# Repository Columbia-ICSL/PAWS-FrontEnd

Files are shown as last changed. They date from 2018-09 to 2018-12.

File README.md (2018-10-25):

# README #

This repository contains the code, pcb design, and documentation for the **Pedestrian Audio Wearable System (PAWS)** front-end, headset, embedded platform.

PAWS is a low-power connected system for improving pedestrian safety in current and future smart cities. PAWS uses microphones embedded into a headset combined with low-power feature extraction, signal processing, and machine learning, for detecting, localizing, and providing alerts of oncoming vehicles to pedestrians in noisy environments.

* Note: The PAWS project was at some point known as SEUS, which is why SEUS is used at some points rather than PAWS.

The contents of this repository are summarized below.

* **PAWS**: Contains the PAWS front-end source code and designs.
	* nordic_nRF52: Contains the project files for building and flashing the firmware for the Nordic nRF52 BLE chip used for wireless communication with the PAWS smartphone application.
	* stm32f4: Contains the project files for building and flashing the firmware for the STM32F4 chip used for feature extraction in PAWS.
	* pcb: Contains the pcb schematics, designed using Altium Circuitmaker, for the PAWS embedded platform as well as documentation for how to maintain the PAWS headset. The platform uses a STM32F4 Chip for feature extraction + the Nordic nRF52 BLE chip for transmission to the smartphone.
* **PAWS_LE**: Contains the PAWS LE front-end source code and designs. PAWS LE is the low-energy variant of PAWS and has finer granularity car localization, achieved by using a technique called *Angle via Polygonal Regression (AvPR)*.
	* nordic_nRF52: Contains the project files for building and flashing the firmware for the Nordic nRF52 BLE chip used for wireless communication with the PAWS LE smartphone application.
	* pcb: Contains the pcb schematics, designed using Altium Circuitmaker, for the PAWS LE embedded platform. The platform uses a custom-build ASIC for relative delay extraction + the Nordic nRF52 BLE chip for transmission to the smartphone.

# Reproducing the PAWS system

To reproduce the PAWS system, you must first install the PAWS smartphone application; details on how to do this can be found in the PAWS-Smartphone repository.

Next, you must reproduce the PAWS front-end PCB. Details on how to do this can be found in the **./PAWS** folder.

# Reproducing the PAWS LE System

To reproduce the PAWS LE system, you must first install the PAWS LE smartphone application; details on how to do this can be found in the [PAWS-Smartphone repository](https://github.com/Columbia-ICSL/PAWS-Smartphone).

Next, you must reproduce the PAWS LE front-end PCB. Details on how to do this can be found in the **./PAWS_LE** folder.

# More About the PAWS Project
To learn more about PAWS, please visit our [project page](http://icsl.ee.columbia.edu/projects/seus), or contact us at: [stephen.xia@columbia.edu](stephen.xia@columbia.edu). 	 
	
This repository is part of the **Pedestrian Audio Wearable System (PAWS)** project of the **Intelligent and Connected Systems Lab (ICSL)**, Columbia University.
For more information about our latest projects, please visit our [group website](http://icsl.ee.columbia.edu).

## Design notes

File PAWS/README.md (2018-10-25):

# PAWS Front-End README #

This folder contains the pcb files necessary to produce the PAWS PCB, the STM32f4 MCU firmware for feature extraction, as well as the firmware for the BLE chip that is used to communicate with the smartphone application.

* Note: The PAWS project was at some point known as SEUS, which is why SEUS is used at some points rather than PAWS.

# Reproducing the PAWS Front-End System

* Fabricate the pcb according to the schematic and Altium Circuit Maker Files in **./pcb/PAWS_pcb**.
* Fabricate the MEMS microphone inputs. The system requires four microphone inputs; the schematic for one microphone can be found in **./pcb/MEMS_pcb**, which can be replicated four times.
* Alternatively, you can directly access the projects on the Altium CircuitMaker software or your web browser [here (PAWS pcb)](https://circuitmaker.com/Projects/Details/Stephen-Xia/ICSL-PS-Combined) and [here (MEMS pcb)](https://workspace.circuitmaker.com/Projects/Details/Stephen-Xia/MEMSMICV0).
* You can view the pcb designs and generate the gerber files for fabrication using [Altium Circuitmaker](https://circuitmaker.com/), a free pcb designing software provided by Altium. After downloading the software, create a new project and import the source files to view the design and components. 

* Once the PCB is assembled, the Nordic nRF52 (BMD-300) chip can be flashed using the firmware located in **./nordic_nRF52/pca10040/s132/arm5_no_packs/_build/nrf52832_xxaa.hex**.
* Additionally, the STM32f4 chip can be flashed using the firmware located in **./stm32f4/MDK-ARM/STM32F446xx/STM32F446xx.hex**.
* Instructions for flashing the STM32f4 and Nordic nRF52 (BMD-300) can be found in **./pcb./SEUS_embedded_front_Rev_0_1_documentation.pdf**. The procedure detailed in this file requires a [STM32NUCLEO](https://www.st.com/en/ecosystems/stm32-nucleo.html?querycriteria=productId=SC2003) and a [Nordic nRF52 DK](https://www.nordicsemi.com/eng/Products/Bluetooth-low-energy/nRF52-DK).

# Building and Flashing Your Own Source Code

Instructions on building your own source code and required libraries for the STM32f4 MCU for feature extraction can be found in the [STM website](https://www.st.com/en/evaluation-tools/nucleo-f446re.html).

Instructions on building your own source code and required libraries for the Nordic nRF52 Chip for wireless transmission can be found in the [Nordic website](https://infocenter.nordicsemi.com/index.jsp).
The SDK used to develop this project was the **nRF5 SDK v12.0.0** with SoftDevice **S132 v3.0.0**.

# More About the PAWS Project
To learn more about PAWS, please visit our [project page](http://icsl.ee.columbia.edu/projects/seus), or contact us at: [stephen.xia@columbia.edu](stephen.xia@columbia.edu). 	 
	
This repository is part of the **Pedestrian Audio Wearable System (PAWS)** project of the **Intelligent and Connected Systems Lab (ICSL)**, Columbia University.
For more information about our latest projects, please visit our [group website](http://icsl.ee.columbia.edu).

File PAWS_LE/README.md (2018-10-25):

# PAWS Low Energy Front-End README #

This folder contains the pcb files necessary to produce the PAWS LE PCB, which uses a custom ASIC, as well as the firmware for the BLE chip that is used to communicate with the smartphone application.

* Note: The PAWS project was at some point known as SEUS, which is why SEUS is used at some points rather than PAWS.

# Reproducing the PAWS Low Energy Front-End System

* Fabricate the pcb according to the schematic and Altium Circuit Maker Files in **./pcb/AltiumCMFiles**.
* Alternatively, you can directly access the project on the Altium CircuitMaker software or your web browser [here](https://circuitmaker.com/Projects/Details/Stephen-Xia/ICSL-PS-REV-02).
The design contains the circular PAWS_LE pcb that is embedded into the headset, eight MEMS microphones (only four are needed as inputs to the PAWS_LE system), and a BLE module connector/debugging board.
* The PAWS_LE system can be assembled with just four of the eight MEMS microphones and the PAWS_LE circular pcb.
* You can view the pcb designs and generate the gerber files for fabrication using [Altium Circuitmaker](https://circuitmaker.com/), a free pcb designing software provided by Altium. After downloading the software, create a new project and import the source files to view the design and components. 

* Once the PCB is assembled, the Nordic nRF52 chip can be flashed using the firmware located in **./nordic_nRF52/pca10040/s132/arm5_no_packs/_build/nrf52832_xxaa.hex**.
* Instructions for flashing the Nordic nRF52 (BMD-300) can be found in **./pcb./SEUS_embedded_front_Rev_0_1_documentation.pdf**. This documentation is for the PAWS pcb, rather than the PAWS_LE system, but the instructions for flashing the BLE module is the same. The procedure detailed in this file requires a [Nordic nRF52 DK](https://www.nordicsemi.com/eng/Products/Bluetooth-low-energy/nRF52-DK).

# Building and Flashing Your Own Source Code

Instructions on building your own source code and required libraries for the Nordic nRF52 Chip for wireless transmission can be found in the [Nordic website](https://infocenter.nordicsemi.com/index.jsp).
The SDK used to develop this project was the **nRF5 SDK v12.0.0** with SoftDevice **S132 v3.0.0**.

# More About the PAWS Project
To learn more about PAWS, please visit our [project page](http://icsl.ee.columbia.edu/projects/seus), or contact us at: [stephen.xia@columbia.edu](stephen.xia@columbia.edu). 	 
	
This repository is part of the **Pedestrian Audio Wearable System (PAWS)** project of the **Intelligent and Connected Systems Lab (ICSL)**, Columbia University.
For more information about our latest projects, please visit our [group website](http://icsl.ee.columbia.edu).

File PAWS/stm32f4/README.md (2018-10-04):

# README #

This folder contains the firmware and source code used to generate it for the STM32f4 MCU, used for extraction car location features, in the PAWS headset.

The firmware used in the PAWS system can be found in **./MDK-ARM/STM32F446xx/STM32F446xx.hex**.

Instructions on building your own source code and required libraries for the STM32f4 MCU for feature extraction can be found in the [STM website](https://www.st.com/en/evaluation-tools/nucleo-f446re.html).

The original README included with the STM32f4 project can be found in the **readme.txt** file.

* Note: The PAWS project was at some point known as SEUS, which is why SEUS is used at some points rather than PAWS.

# More About the PAWS Project
To learn more about PAWS, please visit our [project page](http://icsl.ee.columbia.edu/projects/seus), or contact us at: [stephen.xia@columbia.edu](stephen.xia@columbia.edu). 	 
	
This repository is part of the **Pedestrian Audio Wearable System (PAWS)** project of the **Intelligent and Connected Systems Lab (ICSL)**, Columbia University.
For more information about our latest projects, please visit our [group website](http://icsl.ee.columbia.edu).

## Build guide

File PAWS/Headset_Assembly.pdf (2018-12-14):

Assembling the PAWS Headset

I. Items required
- PAWS assembled PCB x 1
- PAWS MEMS_MIC_V0 x 4
- Headset x 1
- We used a model like this one: https://www.amazon.com/IAXSEE-Headphones-Microphone-Lightweight-Smartphones/dp/B07CM2HCC7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
- 1.5V AAA batteries x 3
- AAA battery holder x 1
- Example: https://www.digikey.com/product-detail/en/keystoneelectronics/2478/36-2478-
ND/303823&?gclid=EAIaIQobChMIqrSq3t2d3wIVBiSGCh0LSgU3EAQYBCA BEgLDSfD_BwE
- NOTE: This battery holder was too big to fit in our headset, so we 3D printed a smaller holder and made our own contacts from wires.
- 3.3V CR2032 battery x 1
- CR2032 battery holder x 1
- Power Switch x 1
- We used a switch like this one: https://www.digikey.com/product-detail/en/eswitch/EG2209A/EG1908-ND/101741

II. Assembling the Headset

This document details how to create the PAWS Headset from the PAWS PCB + the 4 MEMS microphones.

Step 1: Assemble PAWS pcb

Generate the PAWS PCB using the design files located here: https://github.com/Columbia-ICSL/PAWS-FrontEnd/tree/master/PAWS/pcb/PAWS_pcb/AltiumCMFiles

The design was generated using Altium CircuitMaker, so you can also access the design files through the software here: https://circuitmaker.com/Projects/Details/Stephen-Xia/ICSL-PS-Combined

Populate the board using the components detailed in the schematics and design. Your populated board will look something like this:

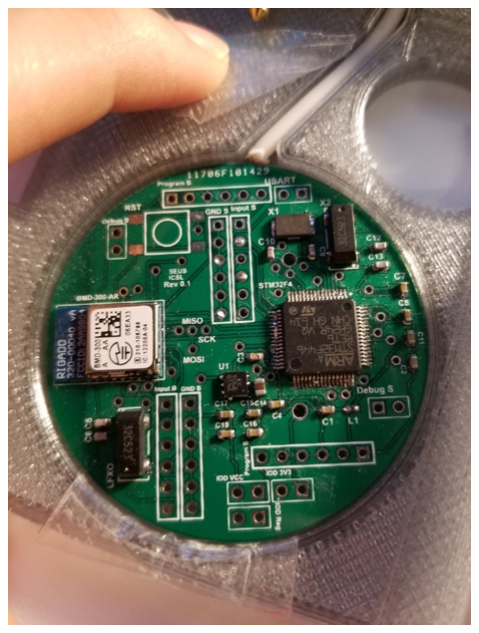
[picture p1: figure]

Make sure you are able to program both the STM32f4 and BMD-300 module (contains Nordic nRF52 BLE chip). Details on how to program the two components can be found: https://github.com/Columbia-ICSL/PAWS-FrontEnd/blob/master/PAWS/pcb/SEUS_embedded_front_Rev_0_1_documentation.pdf

More information on how to program and debug the individual boards can be found:

STM32f4:
https://www.st.com/content/ccc/resource/technical/document/user_manual/98/2e/fa/4b/e0/82/43/b7/DM00105823.pdf/files/DM00105823.pdf/jcr:content/translations/en.DM0010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

Programming BMD-300 using Nordic nRF52 DK: https://devzone.nordicsemi.com/f/nordic-q-a/15520/how-could-i-program-the-bmd-300-with-anrf52-preview-development-kithttps://devzone.nordicsemi.com/f/nordic-q-a/2032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

General information on Nordic nRF52: http://infocenter.nordicsemi.com/index.jsp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

*NOTE: To program the chips, you need to use the STM32 NUCLEO DK and the Nordic nRF52 DK.

STM32f4 DK Can be found here: https://www.digikey.com/product-detail/en/stmicroelectronics/NUCLEO-F446RE/497-15882-ND/5347712

and Nordic nRF52 DK can be found here: https://www.digikey.com/product-detail/en/nordic-semiconductor-asa/NRF52-DK/1490-1053-ND/5773879

Step 2: Assemble 4 MEMS microphones

The PAWS system requires 4 MEMS microphones. You can generate 4+ microphones using the schematic + layouts found here: https://github.com/Columbia-ICSL/PAWS-FrontEnd/tree/master/PAWS/pcb/MEMS_pcb/AltiumCMFiles

The design was generated using Altium CircuitMaker, so you can also access the design files through the software here: https://circuitmaker.com/Projects/Details/Stephen-Xia/MEMSMICV0

Populate the microphones using the components detailed in the schematics and design. Your populated boards will look something like this (depending on the version):

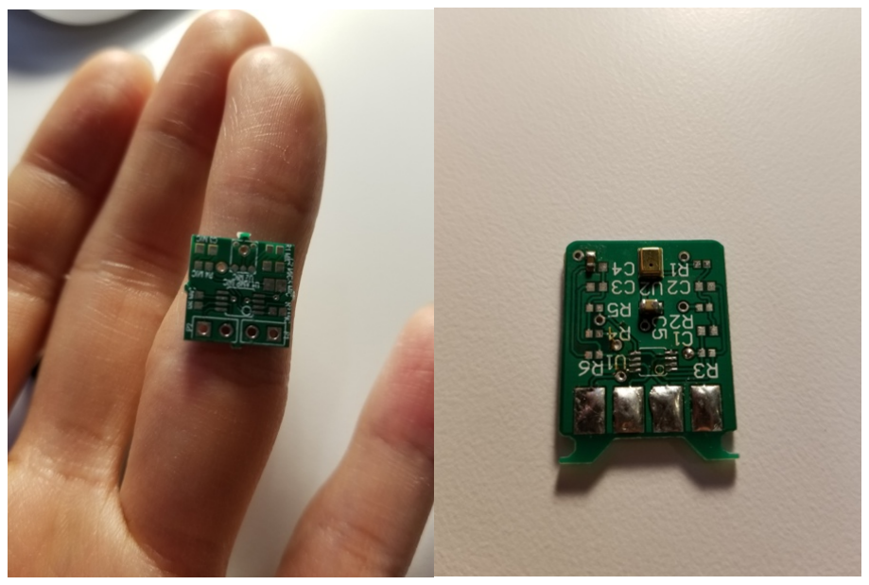
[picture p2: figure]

Step 3: Prepare the headset

The headset will have four microphones mounted on it and will contain the PAWS PCB + batteries. An overview of the headset, with microphones + PCB is highlighted in the following figure.

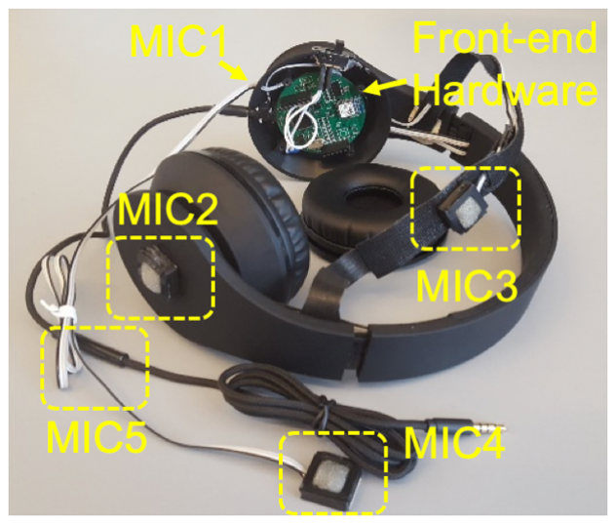
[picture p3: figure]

Note that there is one microphone on the back of the head that is attached by an extra strip of material.

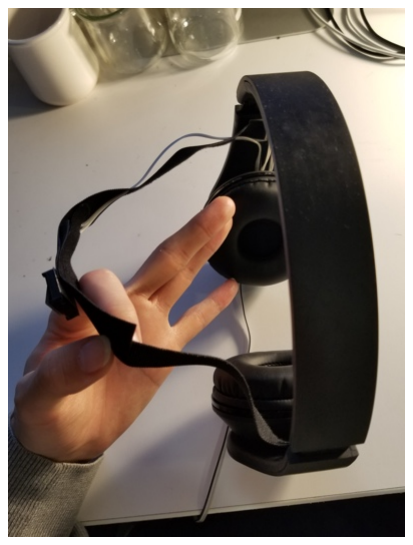
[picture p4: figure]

First, take off both covers of the headset. To do this, remove the cushion, and then unscrew the cover.

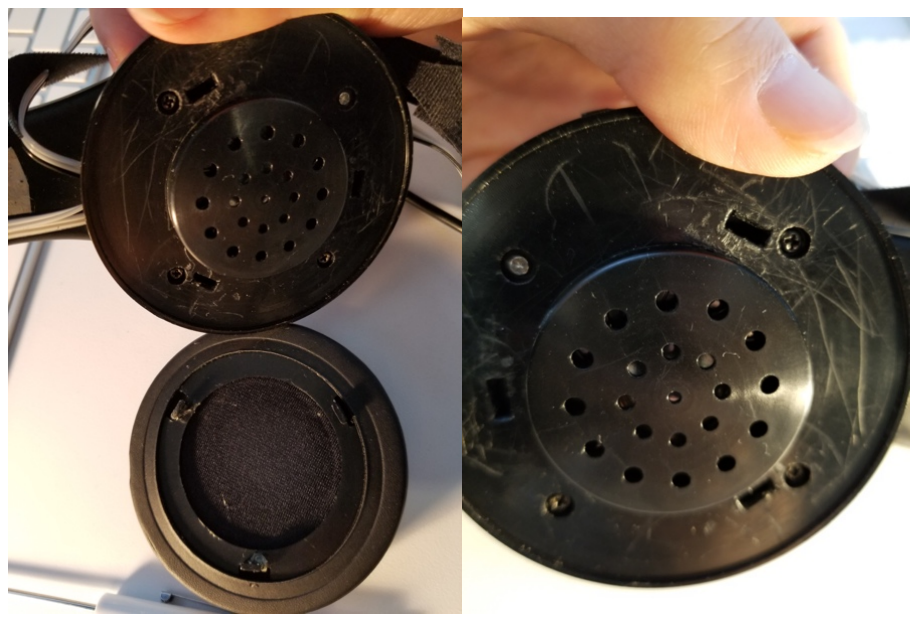
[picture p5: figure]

We need to also drill a few holes in the headset for the microphone wires to come out of. For the two microphones attached one on each side of the headset, drill a small hole on each side:

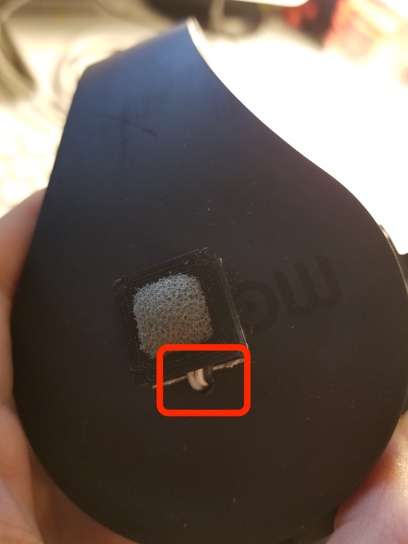
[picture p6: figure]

On one side of the headset, drill a hole on the underside of the cushion for the fourth microphone that is intended to be attached onto the person’s shirt. We drilled the hole on the left ear.

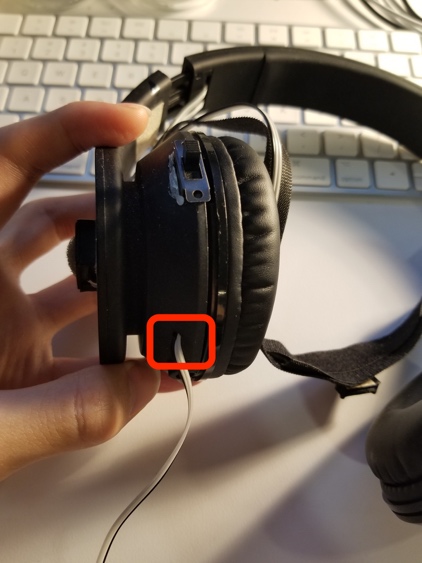
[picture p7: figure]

Make sure there is room for the wires to travel from one side to the other, since one side will hold the pcb and the other side will hold the battery used to power the system.

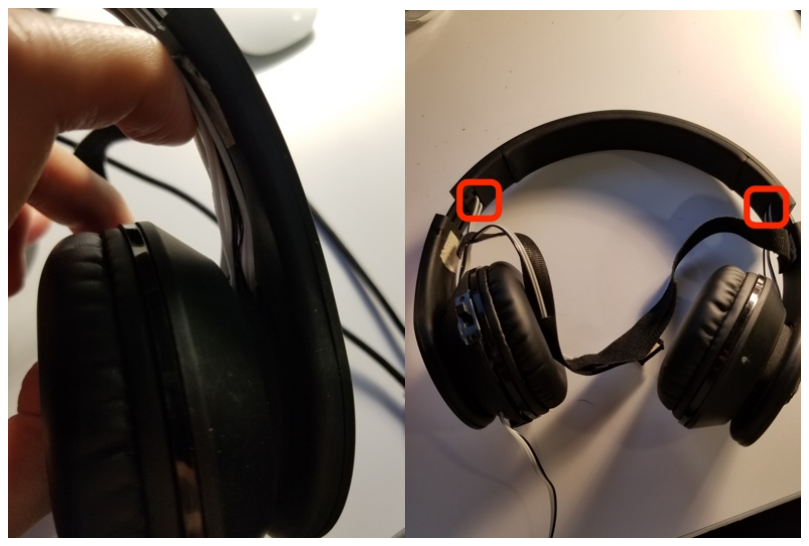
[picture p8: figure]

Step 4: Prepare the PAWS PCB.

Make sure one of the pins from IDD 3V3 is connected to IDD Reg

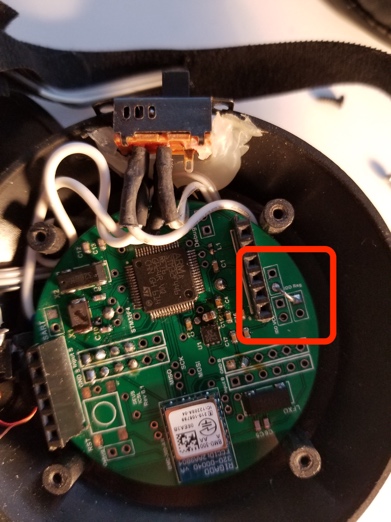
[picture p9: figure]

Step 5: Connect PCB with microphones, switch, and battery

The PAWS PCB is housed in the left ear. The CR2032 batteries + holder can be placed underneath the PCB, while the AAA battery holder will go into the right ear.

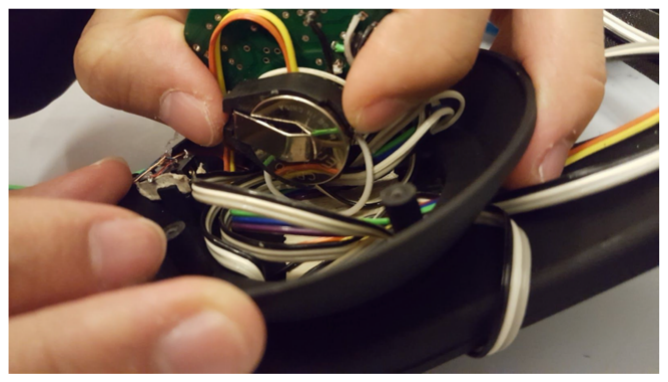
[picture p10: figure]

Connect the negative end of the battery to the PCB GND and connect the positive end of the battery to one of the middle prongs on the switch as shown below. Then, connect the corresponding prong at the end of the switch to the PCB VDD as shown below. This way, the switch will act as a power button; in the figure below, the board is turned on when the switch is to the left.

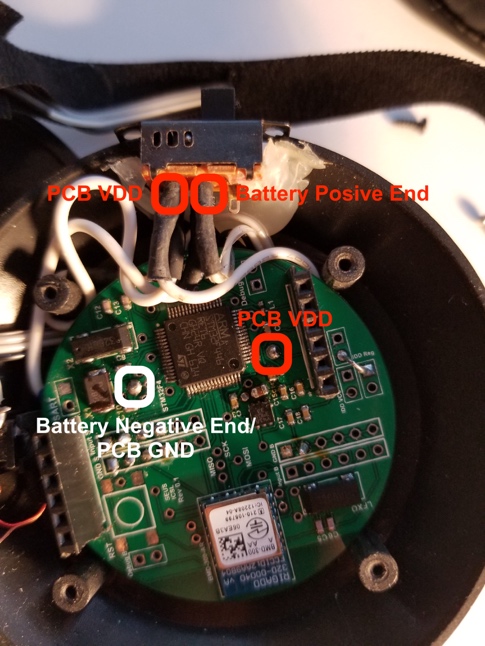
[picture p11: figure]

Next, we have to connect the four microphones + coin cell battery used to power the microphones. Before soldering the microphone connections in place, make sure the wires are looped through the holes created in the headset created in the previous steps that way the microphones will be in the correct place after soldering is complete.

Connect the negative end of the coin cell battery to any of the pins in GND B. Connect the positive end of the battery to the middle prong on the same switch that is attached with the AAA batteries. In the figure below, the prongs you should attach the coin cell battery is underneath the prongs that control the AAA batteries that power the board. Connect the prong on the end of the switch to the VDD pin of each of the four microphones; you will have one wire connected to the prong that breaks out into four wires that power all of the microphones. Now the switch controls power to both the coin cell and the board.

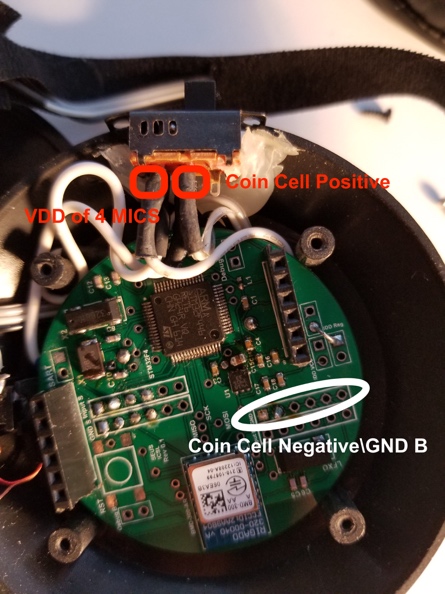
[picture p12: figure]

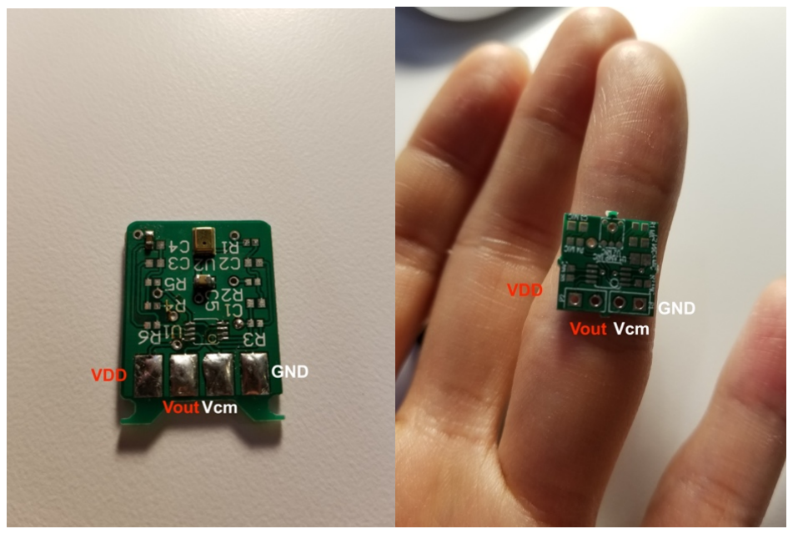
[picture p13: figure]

The VDD of all microphones are all connected to the coin cell and switch; we need to connect each microphone’s Vout and GND pins to the PAWS board. The Vcm pin for each microphone will remain unconnected for this version of PAWS. Connect each of the four microphone’s GND pin to any pin in GND S on the PAWS PCB.

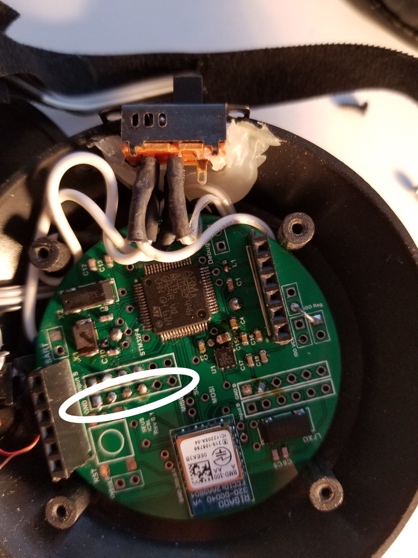
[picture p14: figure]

Next, connect each microphone’s Vout pin to the Input S pins on the PAWS PCB. The order is important if you want to exactly replicate our system.

- Mic 1: Left side
- Mic 2: Right side
- Mic 3: Behind head
- Mic 4: Shirt mic

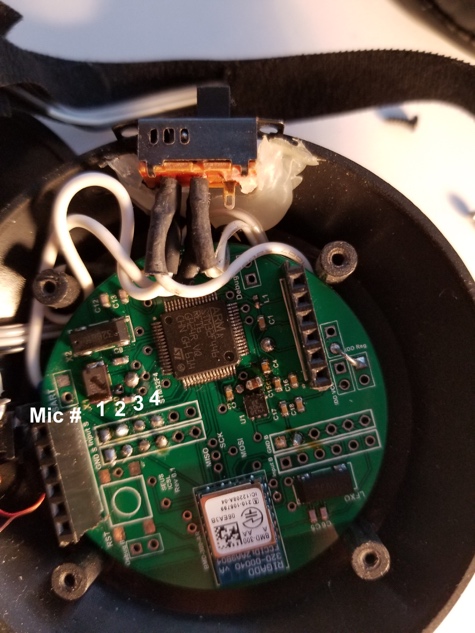
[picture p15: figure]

All the required electrical wiring is complete; reassemble the headset and try it out with the smartphone application.

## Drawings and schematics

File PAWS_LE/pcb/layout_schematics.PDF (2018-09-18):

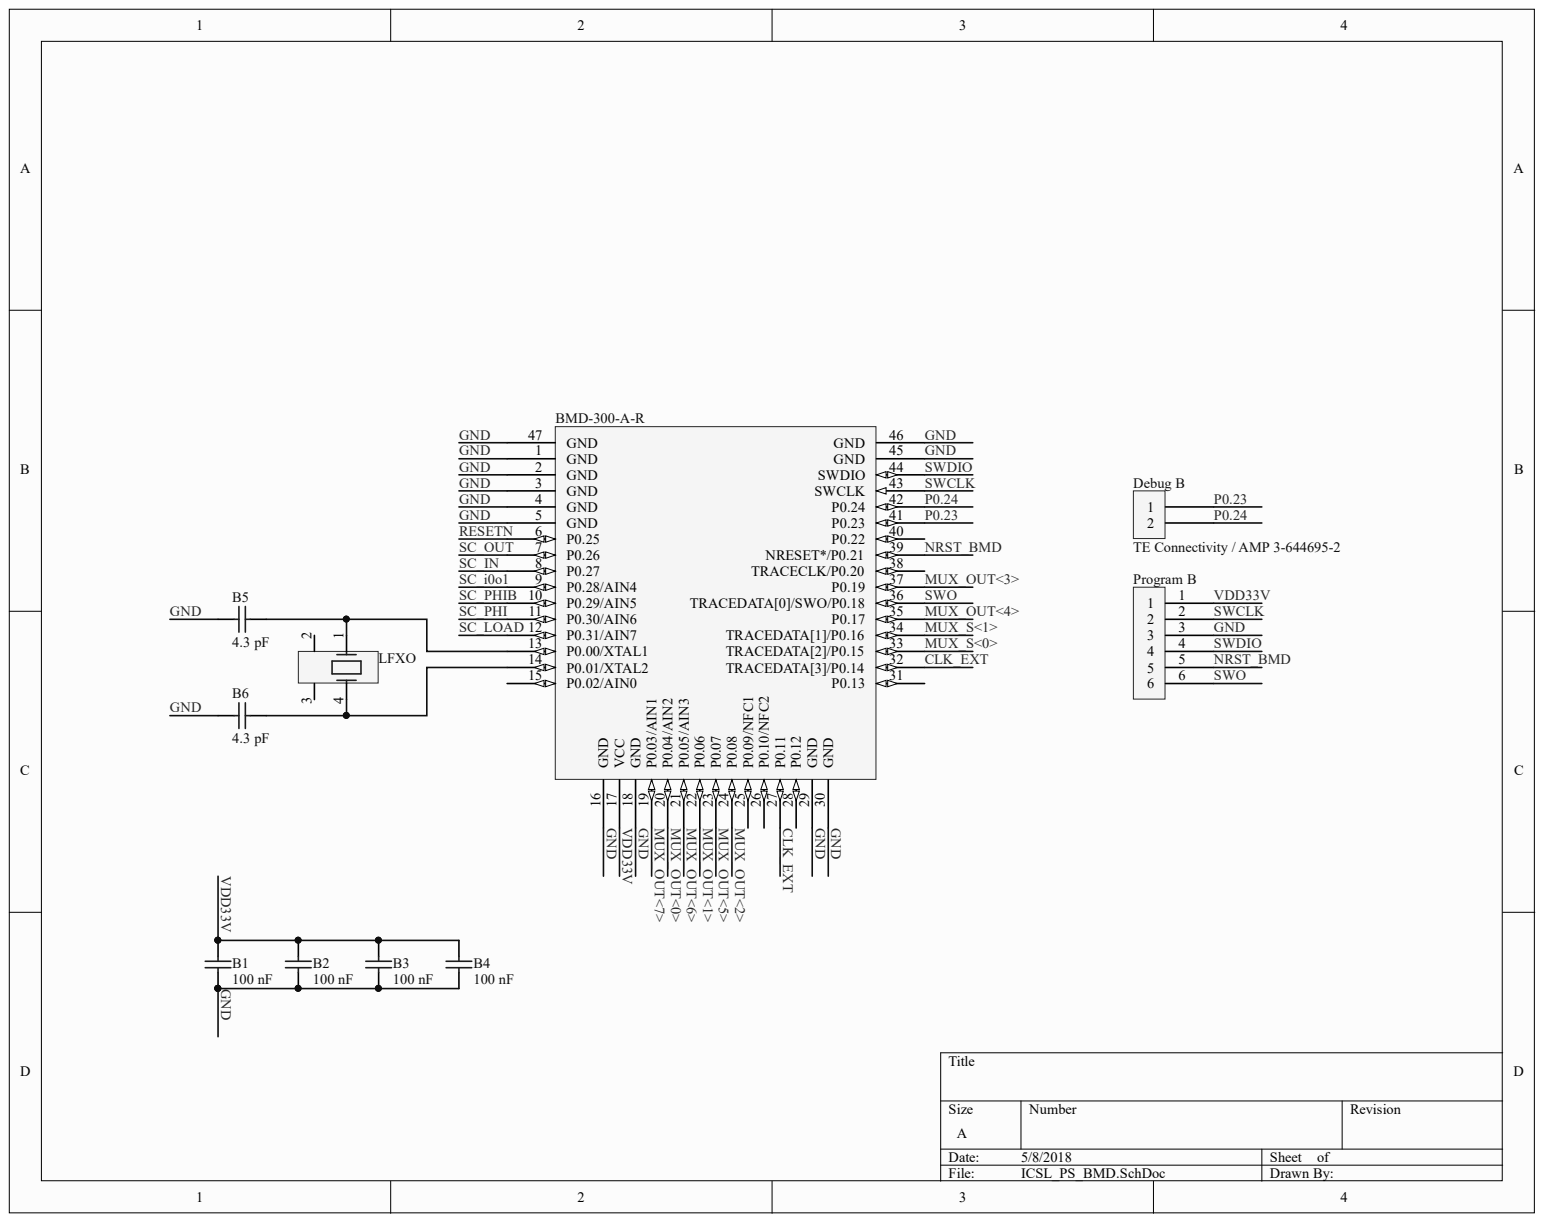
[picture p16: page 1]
Date:; Sheet of; File:; ICSL_PS_BMD.SchDoc; Drawn By:; GND; 46 GND 47; GND 1 GND 2 GND 3; GND 4 GND 5 P0.25 6 P0.26 7 P0.27 8 P0.28/AIN4 9 P0.29/AIN5 10 P0.30/AIN6 11 P0.31/AIN7 12 P0.00/XTAL1 13; VCC 17; P0.03/AIN1 19; P0.04/AIN2 20; P0.05/AIN3 21; P0.09/NFC1 25; P0.10/NFC2 26; D 30 GND 45; Debug B; TE Connectivity / AMP 3-644695-2; Program B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

COLFXO LFXO PIBMD03000A0R014 PIBMD03000A0R014 | P0.01/XTAL2 14

PIBMD03000A0R015 | P0.02/AIN0 15

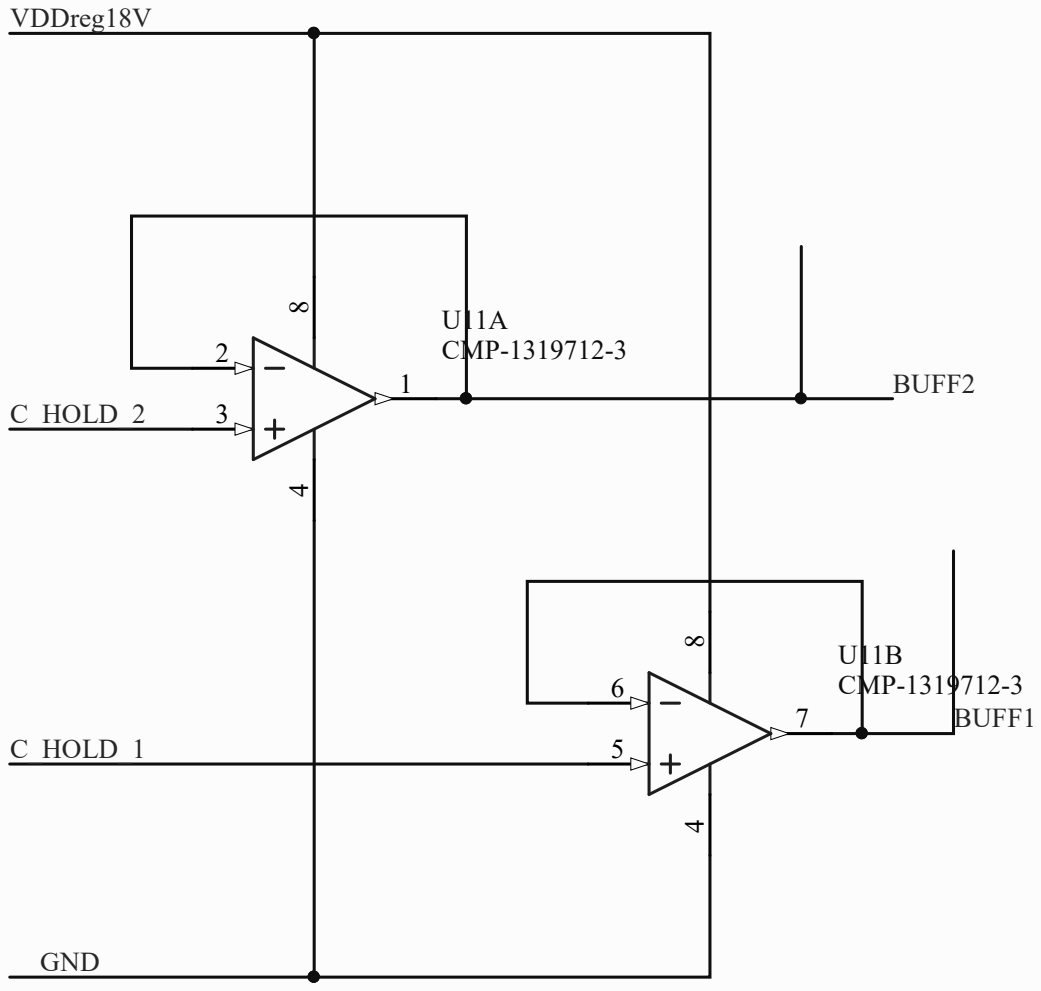
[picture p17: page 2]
File:; ICSL_PS_OPAMP_ES.SchDoc; Drawn By:; PIU1104 PIU1105; PIU1105 NLC0HOLD01; PIU1103 NLC0HOLD02

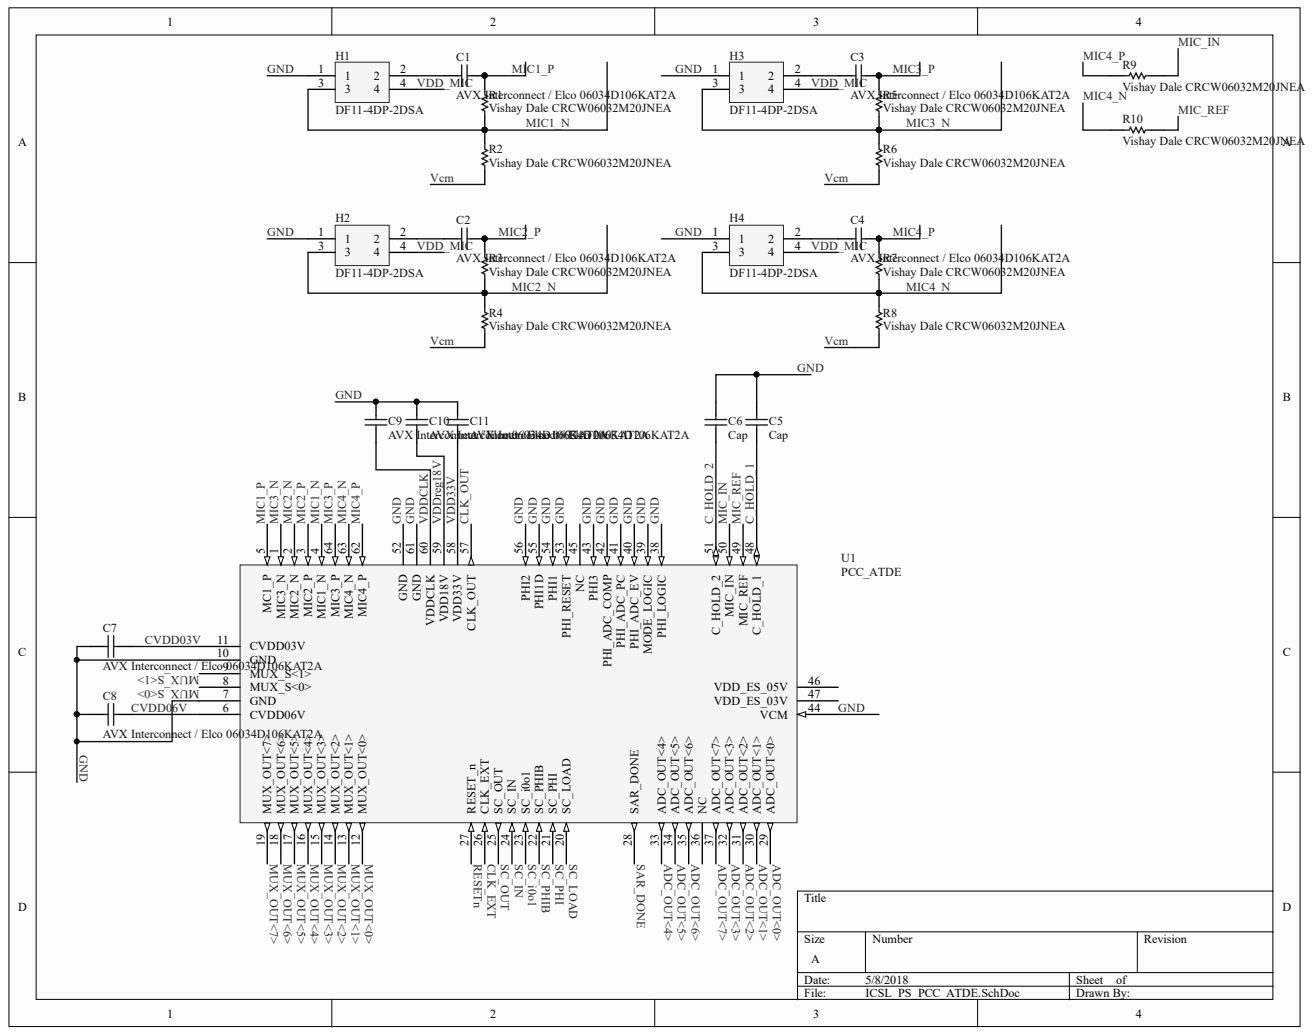
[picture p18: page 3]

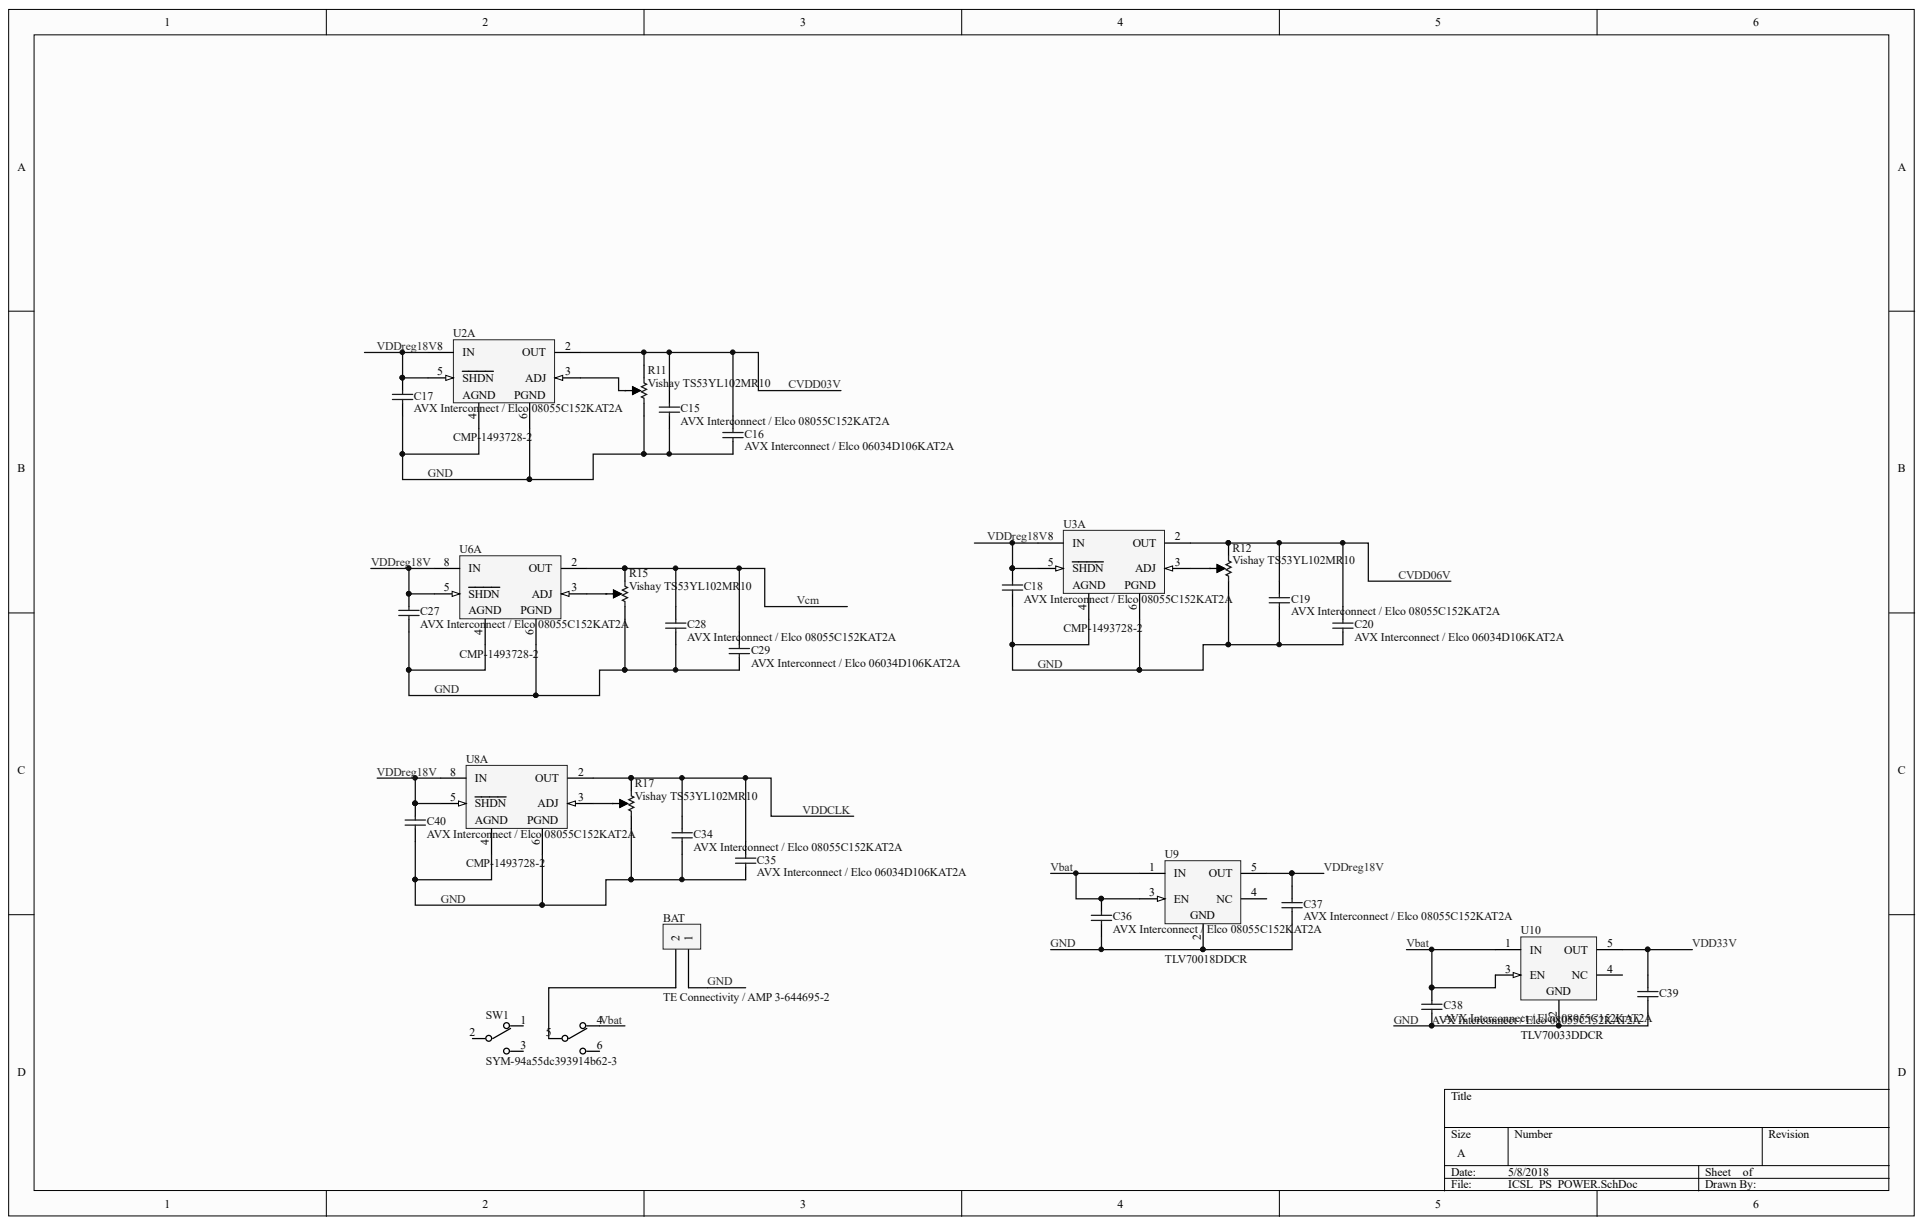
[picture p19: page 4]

CMP-1493728-2

GND | BAT

Size A | Number | Revision

Date: 5/8/2018 | Sheet of
File: ICSL_PS_POWER.SchDoc | Drawn By:

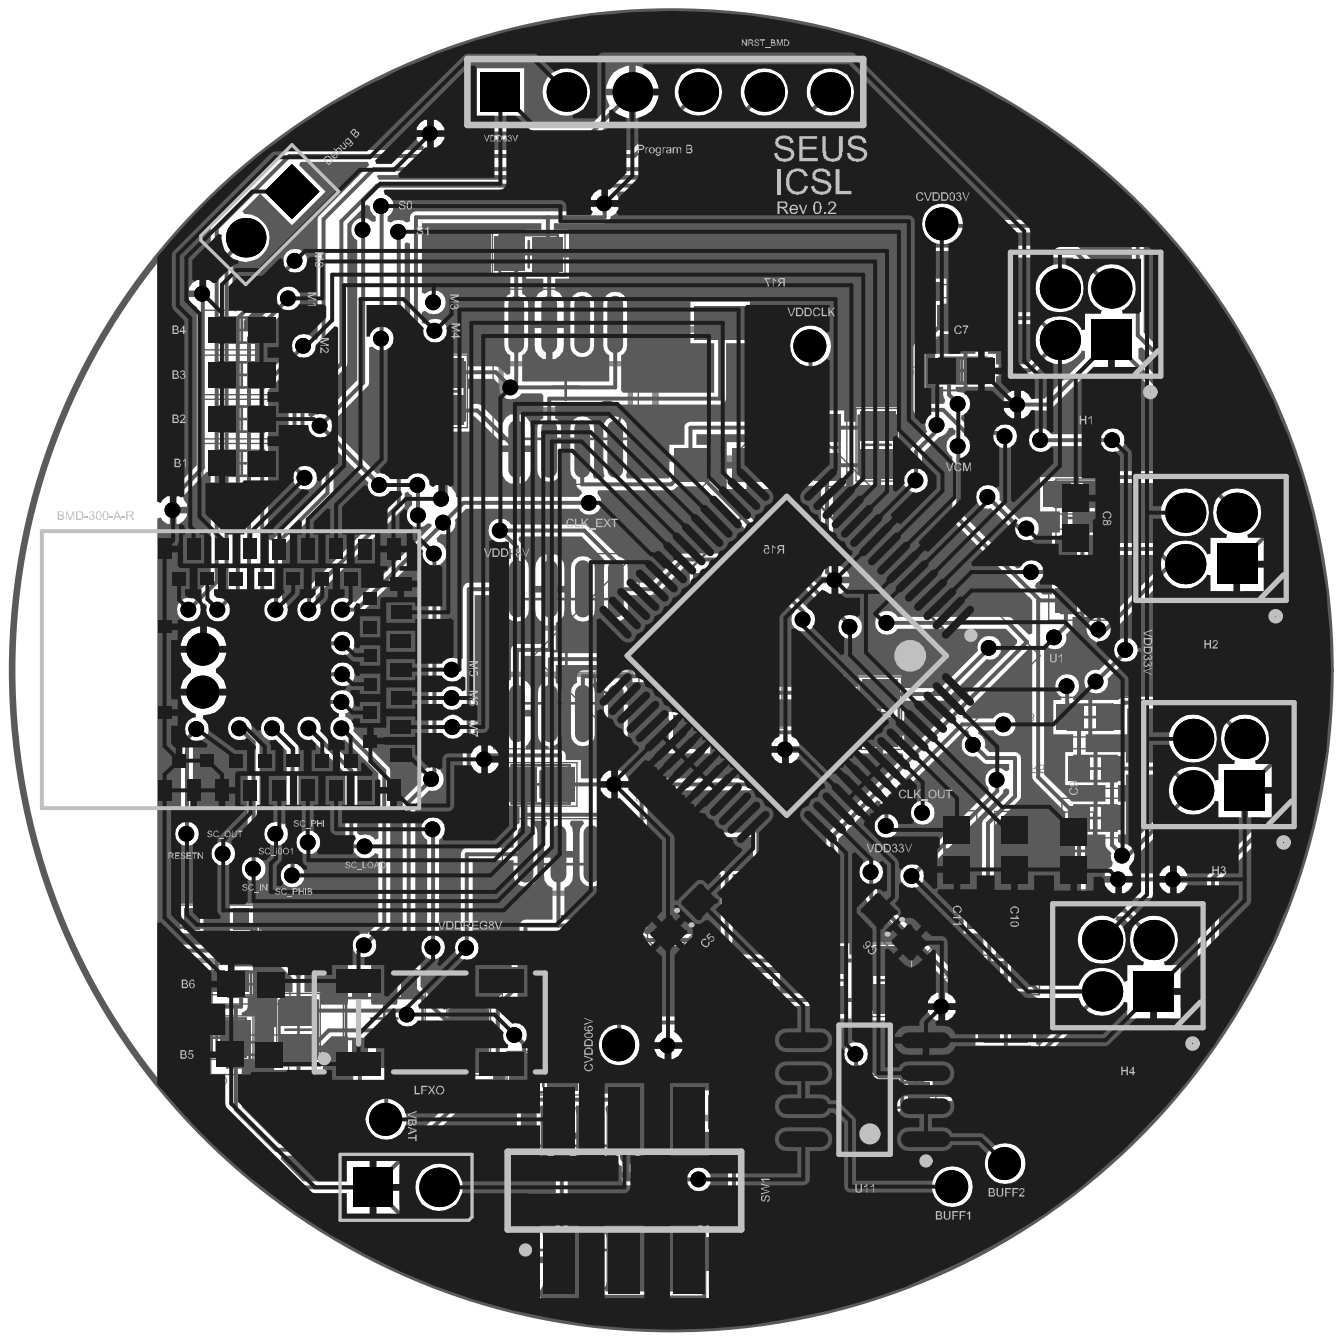
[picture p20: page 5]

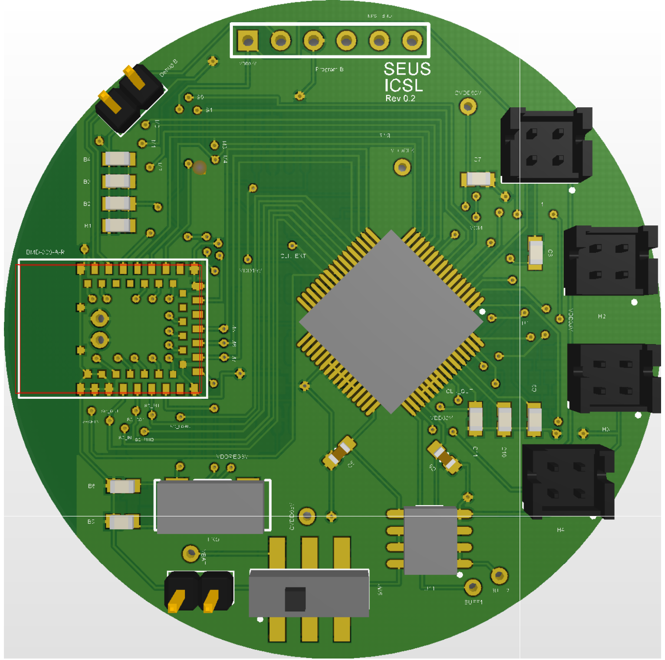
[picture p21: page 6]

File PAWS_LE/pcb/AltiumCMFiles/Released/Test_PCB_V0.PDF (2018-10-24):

# Board Stack

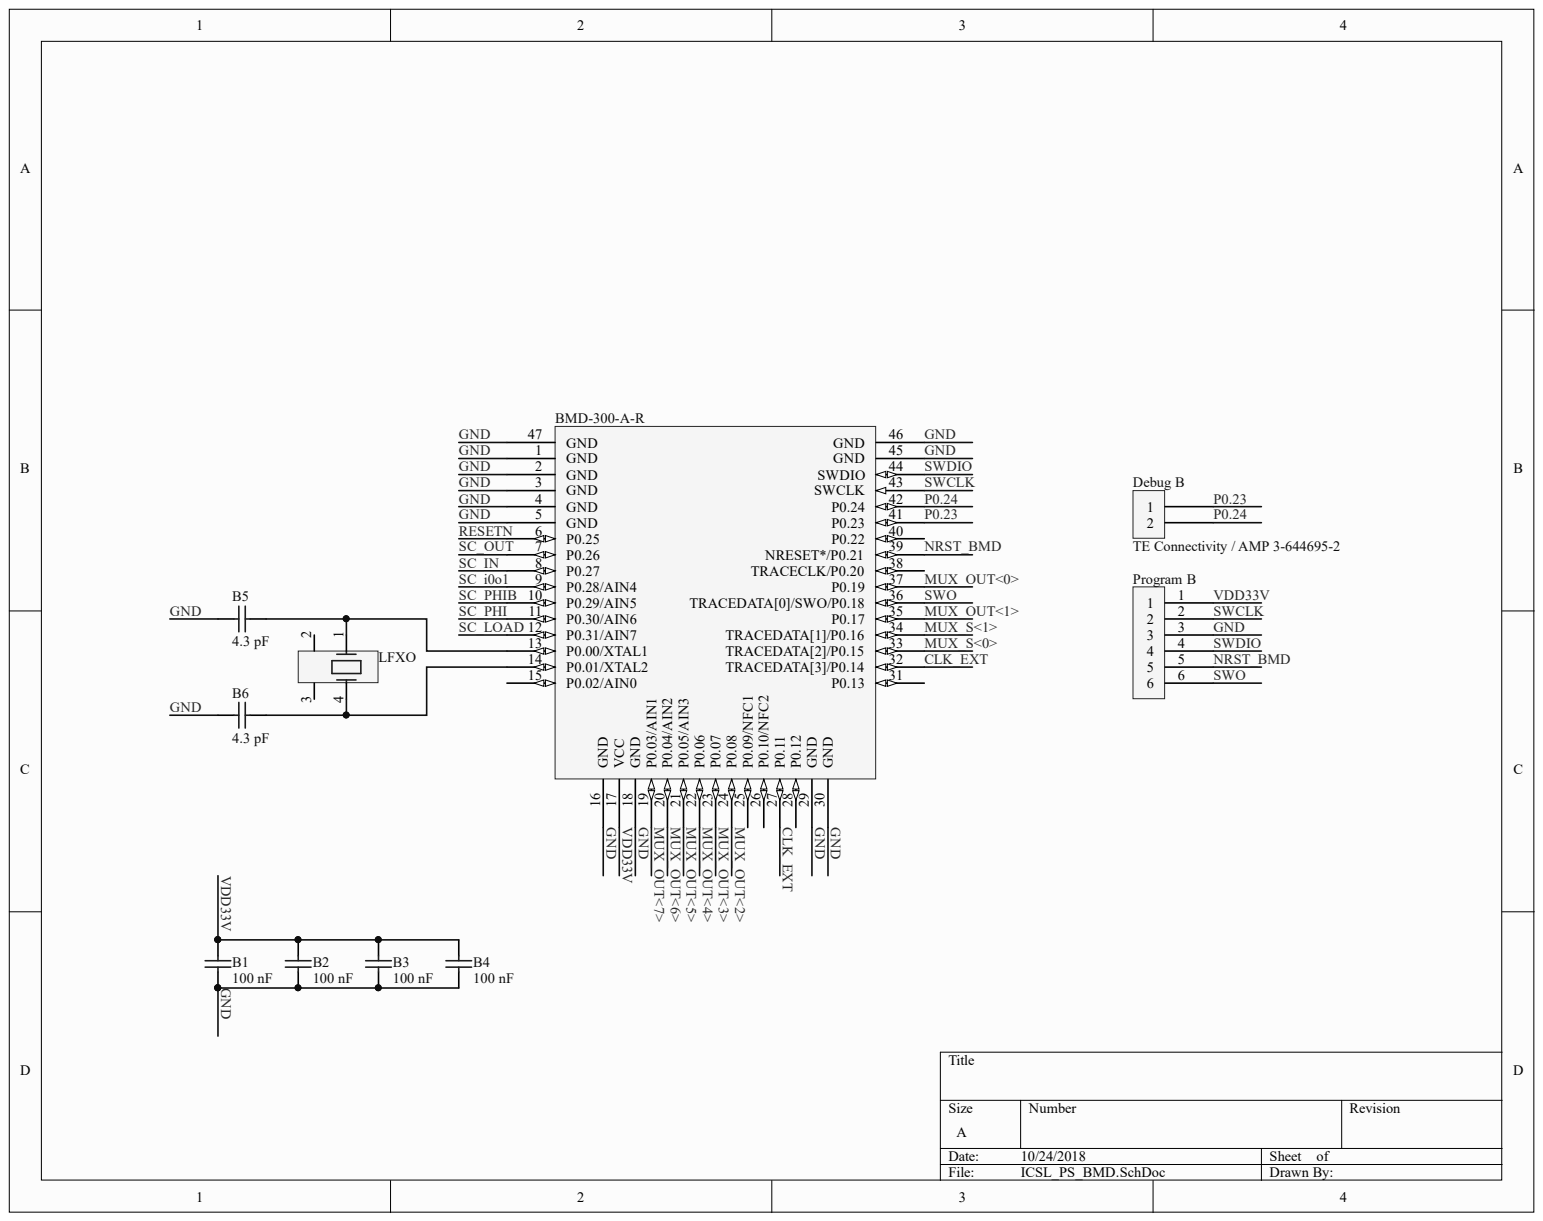
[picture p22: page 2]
Date:; Sheet of; File:; ICSL_PS_BMD.SchDoc; Drawn By:; GND; 46 GND 47; GND 1 GND 2 GND 3; GND 4 GND 5 P0.25 6 P0.26 7 P0.27 8 P0.28/AIN4 9 P0.29/AIN5 10 P0.30/AIN6 11 P0.31/AIN7 12 P0.00/XTAL1 13; VCC 17; P0.03/AIN1 19; P0.04/AIN2 20; P0.05/AIN3 21; P0.09/NFC1 25; P0.10/NFC2 26; D 30 GND 45; Debug B; TE Connectivity / AMP 3-644695-2; Program B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

COLFXO LFXO PIBMD03000A0R014 PIBMD03000A0R014 | P0.01/XTAL2 14

PIBMD03000A0R015 | P0.02/AIN0 15

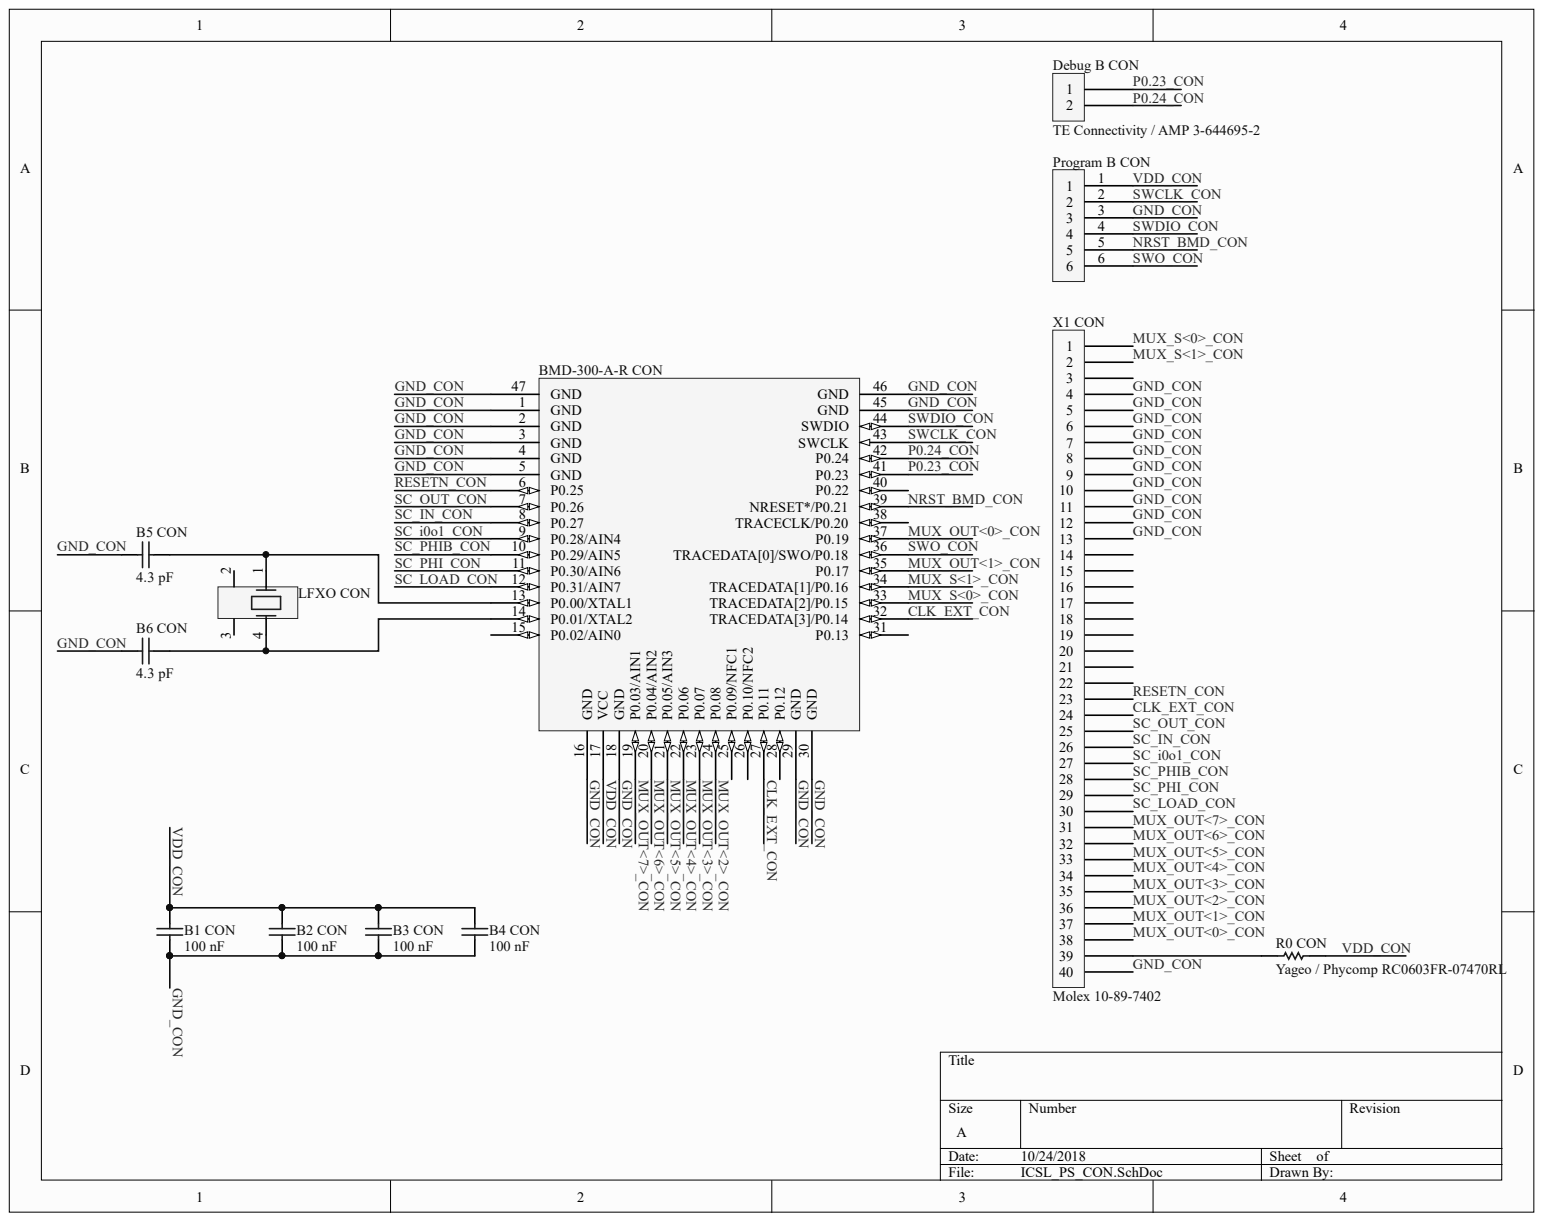
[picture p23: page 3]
GND 1; GND 2; GND 3; GND 16; P0.30/AIN6 11; P0.31/AIN7 12; P0.00/XTAL; P0.01/XTAL2 14; P0.02/AIN0 15; VCC 17; GND 18; P0.03/AIN1 19; P0.04/AIN2 20; P0.05/AIN3 21; P0.09/NFC1 25; P0.10/NFC2 26; P0.12 28 GND 29; GND 30; ebug B CO; E Conne; CON GND; Phycomp RC0603FR-07470RL; PIB1 CON01; PIB1 CON02; COB1 CON; PIB2 CON01; PIB2 CON02; COB2 CON; PIB3 CON01; PIB3 CON02; COB3 CON; PIB4 CON01; PIB4 CON02; COB4 CON; PIB5 CON01; PIB5 CON02; COB5 CON; PIB6 CON01; PIB6 CON02; PIBMD03000A0R CON01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

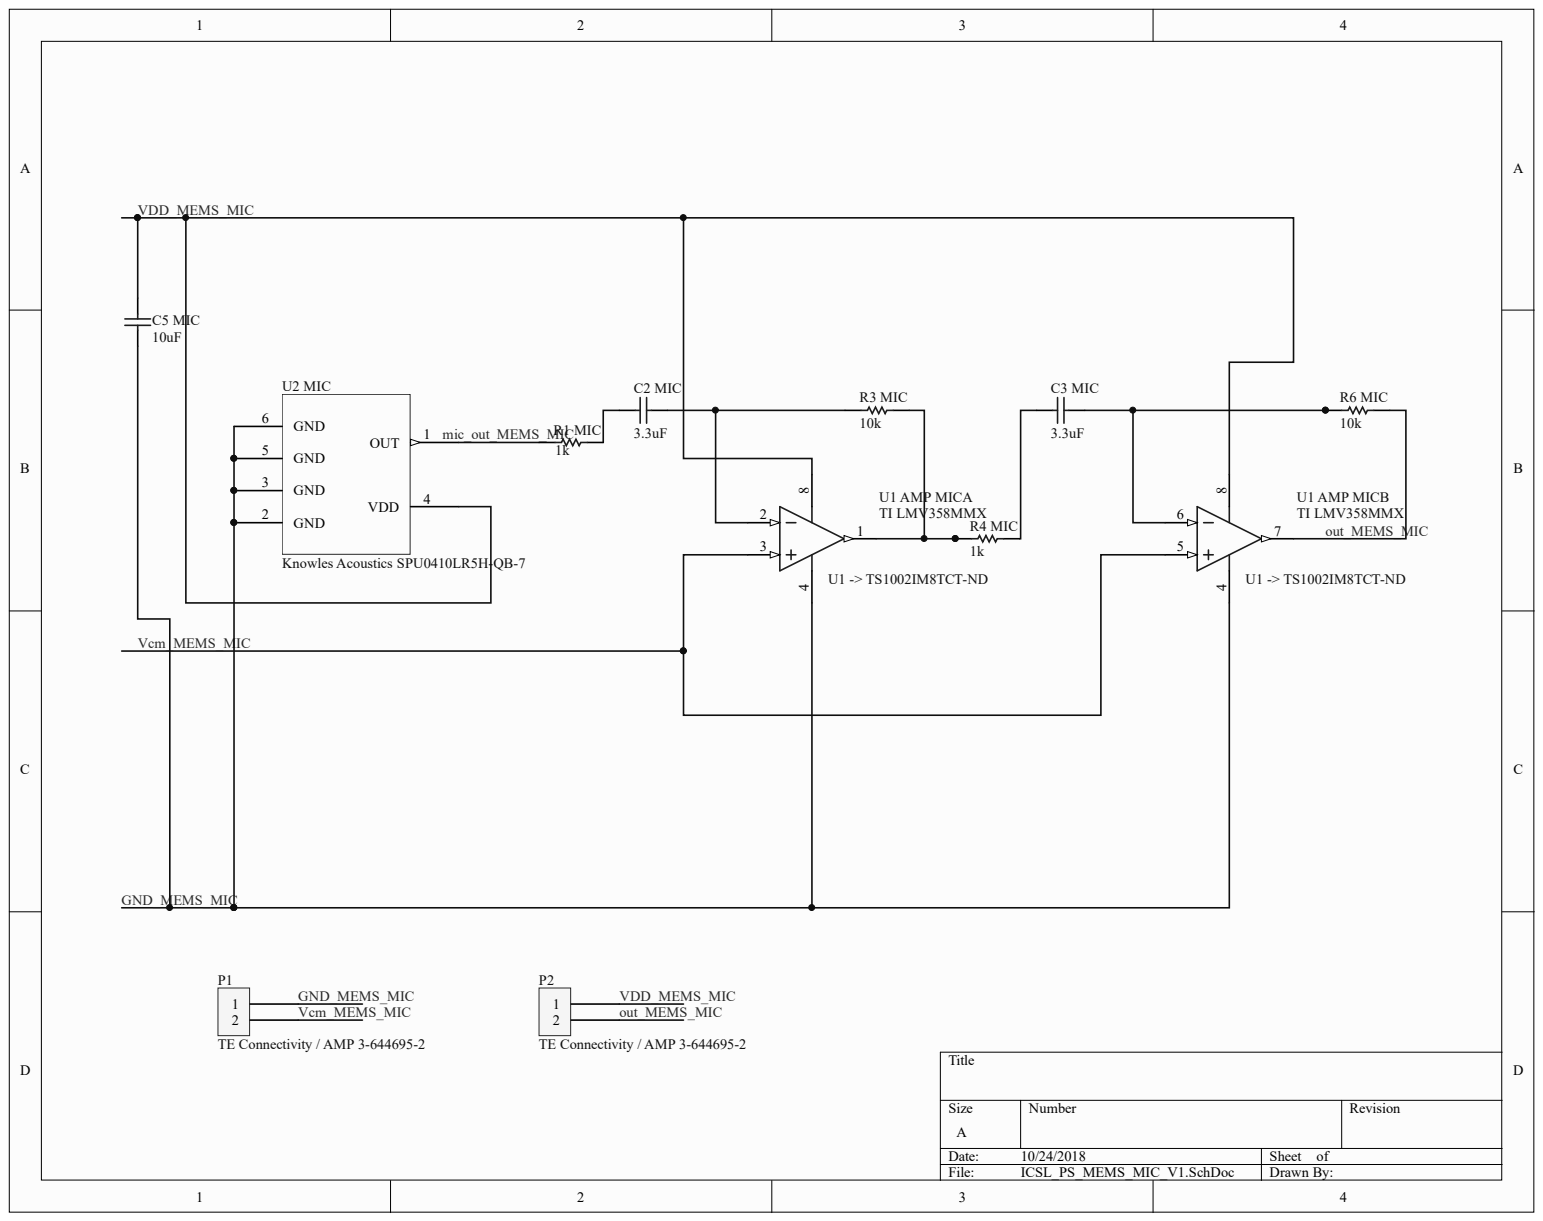
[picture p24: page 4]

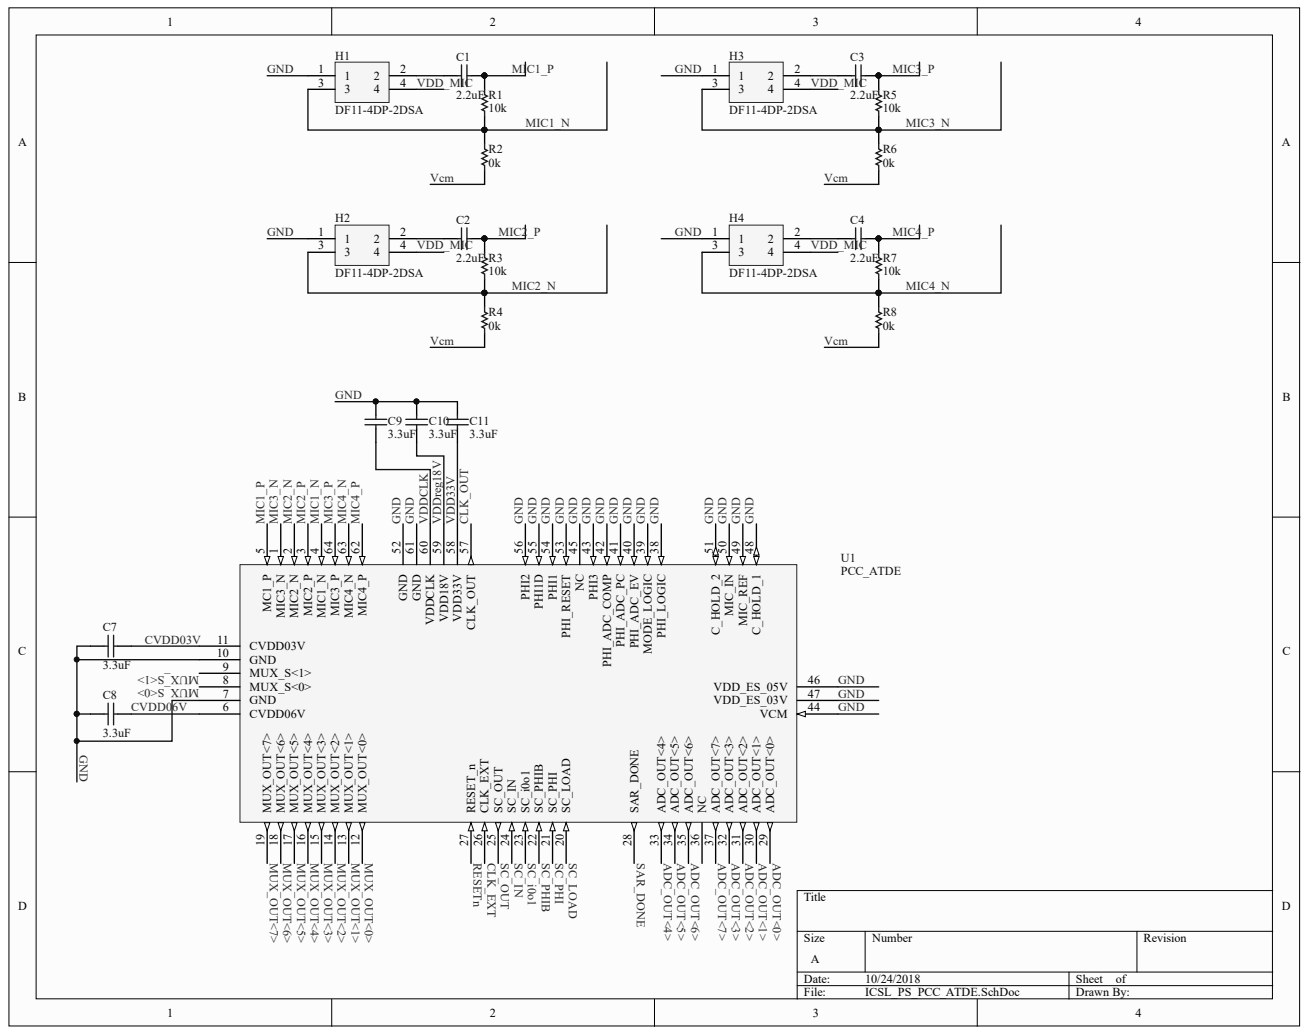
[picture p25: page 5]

CVDD06V

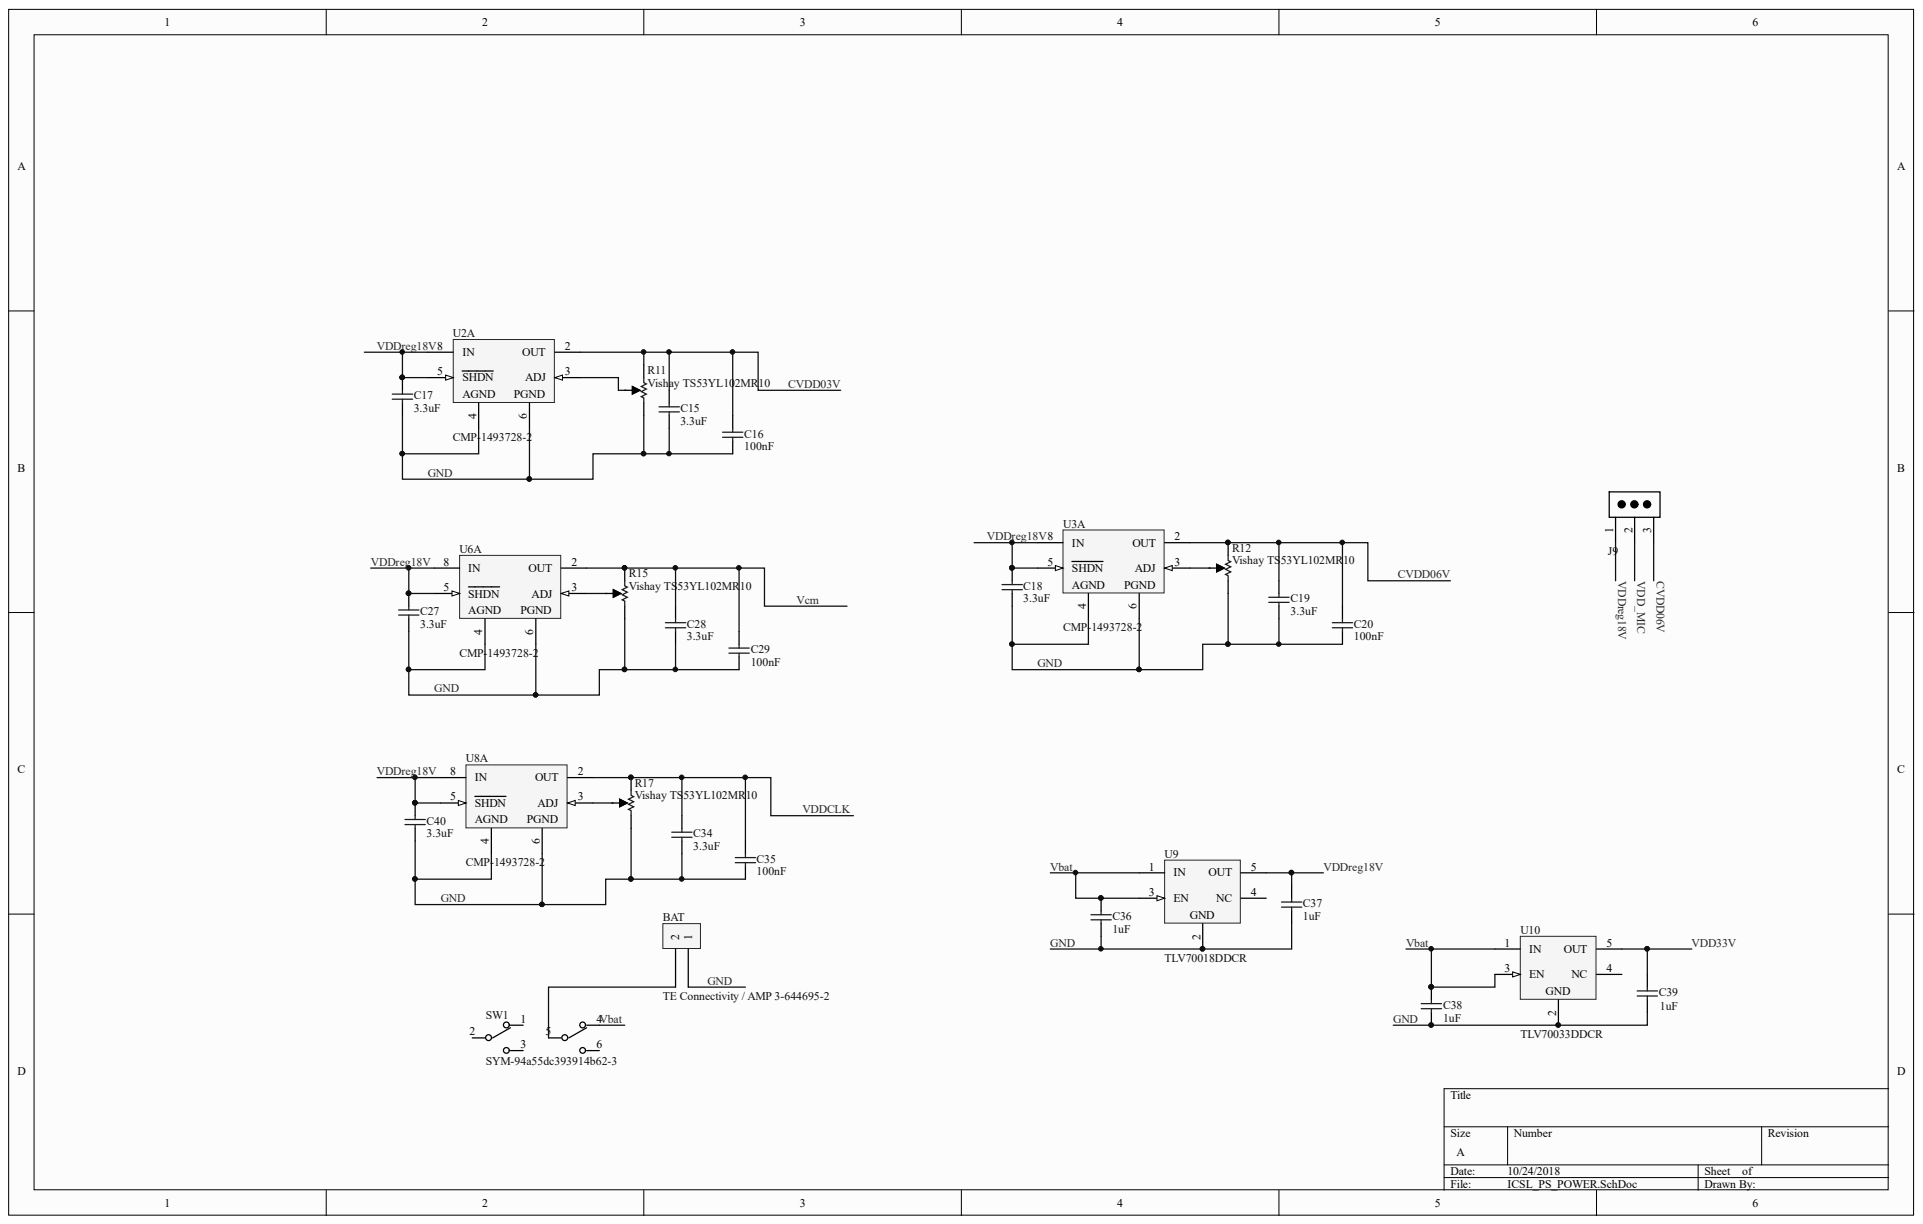
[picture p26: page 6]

CMP-1493728-2

GND | BAT

Size A | Number | Revision

Date: 10/24/2018 | Sheet of
File: ICSL_PS_POWER.SchDoc | Drawn By:

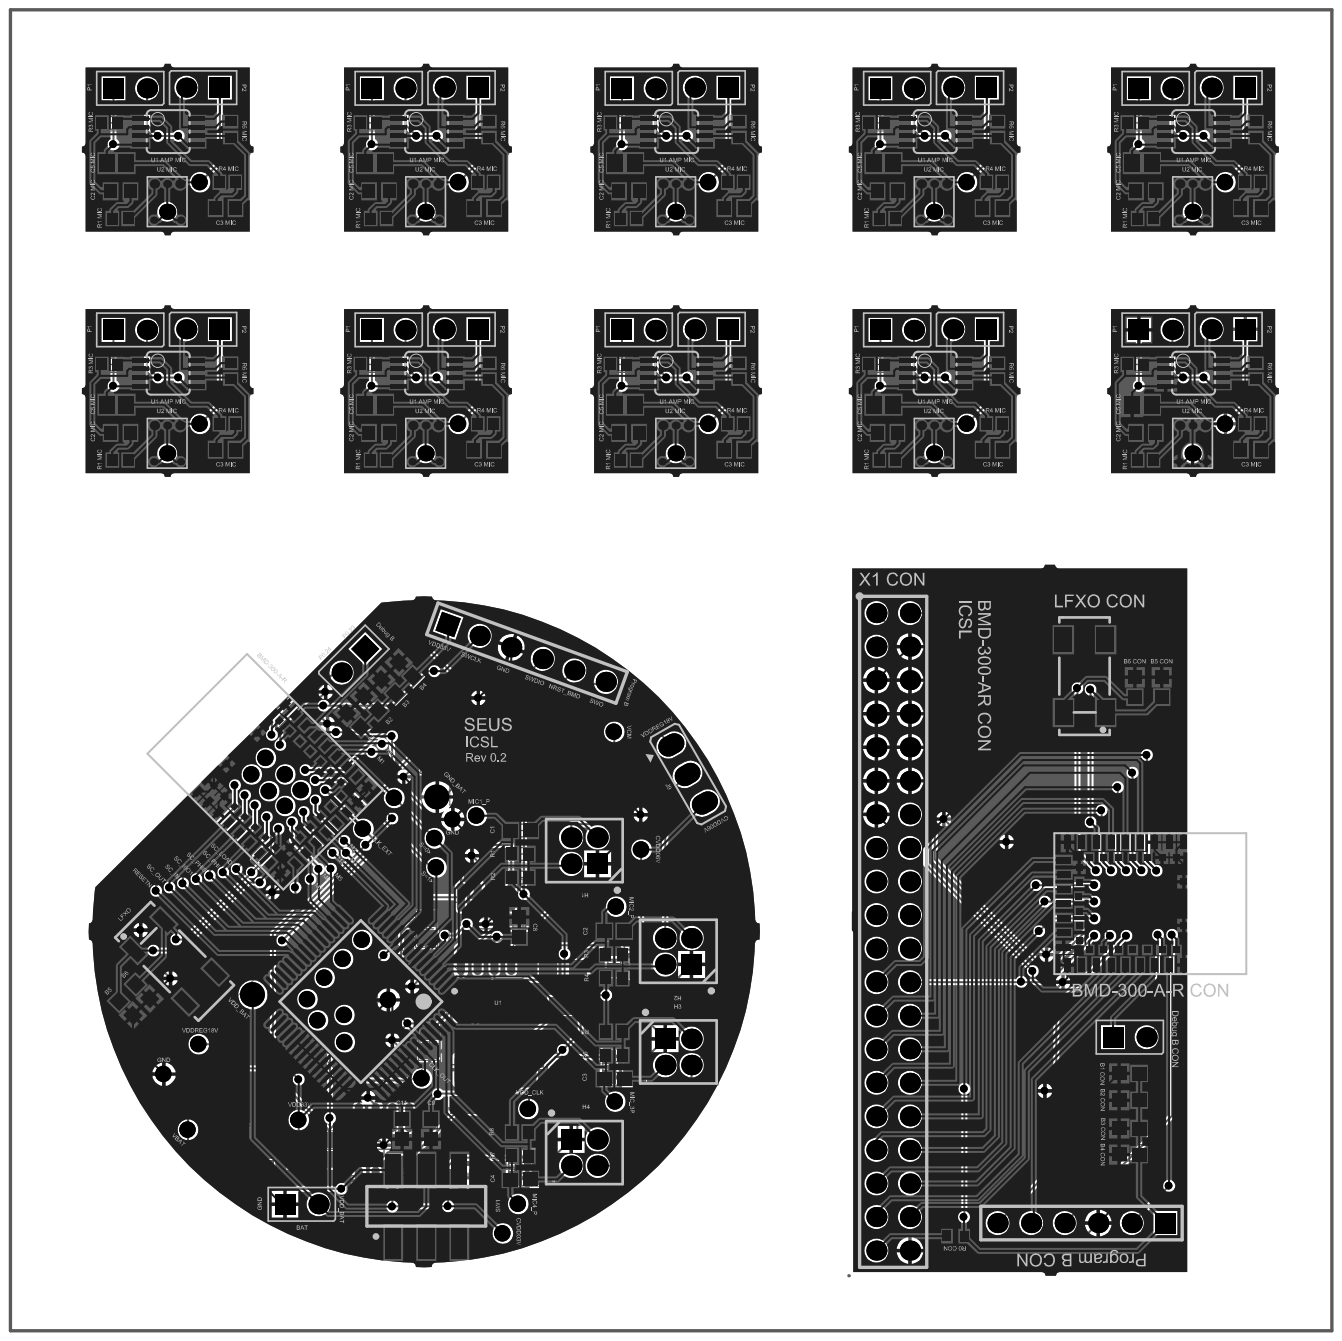
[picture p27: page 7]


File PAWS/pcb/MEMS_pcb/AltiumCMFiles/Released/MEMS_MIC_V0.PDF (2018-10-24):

# Board Stack


Vcm | | Knowles Acoustics SPU0410LR5H-QB-7 | U1 -> TS1002IM8TCT-ND



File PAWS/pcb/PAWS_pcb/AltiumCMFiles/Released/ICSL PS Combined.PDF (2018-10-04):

GND 1; GND 2; GND 3; GND 16; P0.30/AIN6 11; P0.31/AIN7 12; P0.00/XTAL; P0.01/XTAL2 14; P0.02/AIN0 15; VCC 17; GND 18; P0.03/AIN1 19; P0.04/AIN2 20; P0.05/AIN3 21; P0.09/NFC1 25; P0.10/NFC2 26; P0.12 28 GND 29; GND 30; VCC SWCL; PI_CS USART_T





# Board Stack






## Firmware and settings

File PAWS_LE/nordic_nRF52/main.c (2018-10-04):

/* Copyright (c) 2014 Nordic Semiconductor. All Rights Reserved.
 *
 * The information contained herein is property of Nordic Semiconductor ASA.
 * Terms and conditions of usage are described in detail in NORDIC
 * SEMICONDUCTOR STANDARD SOFTWARE LICENSE AGREEMENT.
 *
 * Licensees are granted free, non-transferable use of the information. NO
 * WARRANTY of ANY KIND is provided. This heading must NOT be removed from
 * the file.
 *
 *
 * MIT License
 *
 * Copyright (c) 2018, Stephen Xia, Columbia Intelligent and Connected Systems Lab (ICSL), Columbia University
 *
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
 * THE SOFTWARE IS PROVIDED “AS IS”, WITHOUT WARRANTY OF ANY KIND, EXPRESS OR
 * IMPLIED, INCLUDING BUT NOT LIMITED TO THE WARRANTIES OF MERCHANTABILITY,
 * FITNESS FOR A PARTICULAR PURPOSE AND NONINFRINGEMENT. IN NO EVENT SHALL THE
 * AUTHORS OR COPYRIGHT HOLDERS BE LIABLE FOR ANY CLAIM, DAMAGES OR OTHER
 * LIABILITY, WHETHER IN AN ACTION OF CONTRACT, TORT OR OTHERWISE, ARISING FROM,
 * OUT OF OR IN CONNECTION WITH THE SOFTWARE OR THE USE OR OTHER DEALINGS IN THE
 * SOFTWARE.
 */

/** @file
 *
 * @defgroup ble_sdk_uart_over_ble_main main.c
 * @{
 * @ingroup  ble_sdk_app_nus_eval
 * @brief    UART over BLE application main file.
 *
 * This file contains the source code for a sample application that uses the Nordic UART service.
 * This application uses the @ref srvlib_conn_params module.
 */

#include <stdint.h>
#include <string.h>
#include "nordic_common.h"
#include "nrf.h"
#include "nrf_delay.h"
#include "ble_hci.h"
#include "ble_advdata.h"
#include "ble_advertising.h"
#include "ble_conn_params.h"
#include "softdevice_handler.h"
#include "app_timer.h"
#include "app_button.h"
#include "ble_nus.h"
#include "app_uart.h"
#include "app_util_platform.h"
#include "bsp.h"
#include "bsp_btn_ble.h"
#include "nrf_drv_pwm.h"
#include "nrf_drv_gpiote.h"

#define IS_SRVC_CHANGED_CHARACT_PRESENT 0                                           /**< Include the service_changed characteristic. If not enabled, the server's database cannot be changed for the lifetime of the device. */

#if (NRF_SD_BLE_API_VERSION == 3)
#define NRF_BLE_MAX_MTU_SIZE            GATT_MTU_SIZE_DEFAULT                       /**< MTU size used in the softdevice enabling and to reply to a BLE_GATTS_EVT_EXCHANGE_MTU_REQUEST event. */
#endif

#define APP_FEATURE_NOT_SUPPORTED       BLE_GATT_STATUS_ATTERR_APP_BEGIN + 2        /**< Reply when unsupported features are requested. */

#define CENTRAL_LINK_COUNT              0                                           /**< Number of central links used by the application. When changing this number remember to adjust the RAM settings*/
#define PERIPHERAL_LINK_COUNT           1                                           /**< Number of peripheral links used by the application. When changing this number remember to adjust the RAM settings*/

#define DEVICE_NAME                     "Nordic_UART_0"                               /**< Name of device. Will be included in the advertising data. */
#define NUS_SERVICE_UUID_TYPE           BLE_UUID_TYPE_VENDOR_BEGIN                  /**< UUID type for the Nordic UART Service (vendor specific). */

#define APP_ADV_INTERVAL                64                                          /**< The advertising interval (in units of 0.625 ms. This value corresponds to 40 ms). */
#define APP_ADV_TIMEOUT_IN_SECONDS      180                                         /**< The advertising timeout (in units of seconds). */

#define APP_TIMER_PRESCALER             0                                           /**< Value of the RTC1 PRESCALER register. */
#define APP_TIMER_OP_QUEUE_SIZE         4                                           /**< Size of timer operation queues. */

#define MIN_CONN_INTERVAL               MSEC_TO_UNITS(7.5, UNIT_1_25_MS)             /**< Minimum acceptable connection interval (20 ms), Connection interval uses 1.25 ms units. */
#define MAX_CONN_INTERVAL               MSEC_TO_UNITS(20, UNIT_1_25_MS)             /**< Maximum acceptable connection interval (75 ms), Connection interval uses 1.25 ms units. */
#define SLAVE_LATENCY                   0                                           /**< Slave latency. */
#define CONN_SUP_TIMEOUT                MSEC_TO_UNITS(4000, UNIT_10_MS)             /**< Connection supervisory timeout (4 seconds), Supervision Timeout uses 10 ms units. */
#define FIRST_CONN_PARAMS_UPDATE_DELAY  APP_TIMER_TICKS(5000, APP_TIMER_PRESCALER)  /**< Time from initiating event (connect or start of notification) to first time sd_ble_gap_conn_param_update is called (5 seconds). */
#define NEXT_CONN_PARAMS_UPDATE_DELAY   APP_TIMER_TICKS(30000, APP_TIMER_PRESCALER) /**< Time between each call to sd_ble_gap_conn_param_update after the first call (30 seconds). */
#define MAX_CONN_PARAMS_UPDATE_COUNT    3                                           /**< Number of attempts before giving up the connection parameter negotiation. */

#define DEAD_BEEF                       0xDEADBEEF                                  /**< Value used as error code on stack dump, can be used to identify stack location on stack unwind. */

#define UART_TX_BUF_SIZE                256                                         /**< UART TX buffer size. */
#define UART_RX_BUF_SIZE                256                                         /**< UART RX buffer size. */

// Length of messages for the start and stop message to send to STM
#define START_MSG_LEN 5
#define END_MSG_LEN 5

// Constants for dealing with interfacing with xcorr chip
// Max sampling is around 30 kHz
#define XCORR_PWM_PIN 14                           // Pin for PWM clock
#define XCORR_PWM_INTERRUPT_PIN 11                 // Pin for reading the same PWM clock source as the xcorr chip for synchronized reads from the chip
#define XCORR_PWM_PIN_S0 15   // 0 signal pin
#define XCORR_PWM_PIN_S1 16   // 1 signal pin
#define XCORR_PWM_TOP_TICK 5 * 16
#define XCORR_PWM_TOGGLE_TICK 5 * 16/ 2
#define XCORR_NUM_TO_AVERAGE 750  // If reading samples at 30k, this corresponds to sending 20 samples per second
//#define XCORR_NUM_TO_AVERAGE 2500 // Number of values to average for one sample to transmit - with 1 MHz, 100 ticks per period yields txing 20 times per second
//#define XCORR_PWM_TOP_TICK 1600
//#define XCORR_PWM_TOGGLE_TICK 800
//#define XCORR_NUM_TO_AVERAGE 125 // Number of values to average for one sample to transmit - with 1 MHz, 100 ticks per period yields txing 20 times per second


#define XCORR_DATA_PIN_0 3
#define XCORR_DATA_PIN_1 4
#define XCORR_DATA_PIN_2 5
#define XCORR_DATA_PIN_3 6    
#define XCORR_DATA_PIN_4 7
#define XCORR_DATA_PIN_5 8
#define XCORR_DATA_PIN_6 18
#define XCORR_DATA_PIN_7 19

#define XCORR_PHI_PIN 25
#define XCORR_PHIB_PIN 26
#define XCORR_SC_IN_PIN 27
#define XCORR_SC_LOAD_PIN 28
#define XCORR_SC_i0O1_PIN 29
#define XCORR_SC_OUT_PIN 30
#define XCORR_RESETN_PIN 31

#define TX_WINDOW_SIZE 35// Number of bytes to send in one frame

// Pin number for controlling the state of the STM32f446re
#define STM_EXTI_PIN 17

// SCAN CHAIN INPUT
#define SC_size 42

#define SC_EXT_SEL 0,1 // 2
#define SC_DIV_SEL 0,0,0,0 // 4
#define SC_TAP_SEL 0,0,0,0 // 4
#define SC_CLK 0 // 1
#define SC_CLK_ST 0 // 1

#define SC_G 0,1,0 // 3
#define SC_FB_CTRL  0  // 1
#define SC_MAX_VAL 0,1,1,1,1,1,1,0 // 126
#define SC_RSTN 1 // 1

#define SC_FB 0 // 1
#define SC_ATDE_RST 0 // 1

#define SC_ES 0,0,0,0,0,0,0,0,0,0,0,0,0,0,0,0 // 16

static ble_nus_t                        m_nus;                                      /**< Structure to identify the Nordic UART Service. */
static uint16_t                         m_conn_handle = BLE_CONN_HANDLE_INVALID;    /**< Handle of the current connection. */

static ble_uuid_t                       m_adv_uuids[] = {{BLE_UUID_NUS_SERVICE, NUS_SERVICE_UUID_TYPE}};  /**< Universally unique service identifier. */

static uint8_t send = 0;   // Used to see if you can send or not (send = 0 if not connected, 1 if it is connected)
static uint8_t send_first_time = 0;  // Used to make sure the first time you send it begins with the delimiter

static uint8_t connection_char_desc[4] = {70, 82, 69, 68};   // descriptor of the connection characteristic name

// Test data
uint8_t test_data[1] = {65};

//static uint32_t       err_code;
// Start and end messages for STM
static uint8_t start_msg[START_MSG_LEN] = {83, 69, 85, 83, 83};  // SEUSS
static uint8_t end_msg[START_MSG_LEN] = {83, 69, 85, 83, 69};  // SEUSE

// Flags for determining when to start and stop pipeline 
static uint8_t start = 0;
static uint8_t stop = 0;
static uint8_t running = 0;

// Variables for controlling xcorr chip
static nrf_drv_pwm_t m_pwm0 = NRF_DRV_PWM_INSTANCE(0);
uint8_t pwm_polarity_flag = 0;
static uint8_t tx_window[TX_WINDOW_SIZE + 5] = {83, 69, 85, 83, 35, 0, 0, 0, 0, 0, 0, 0, 0, 0, 0, 0, 0, 0, 0, 0, 0, 0, 0, 0, 0, 0, 0, 0, 0, 0, 0, 0, 0, 0, 0, 0, 0, 0, 0, 0};
static uint8_t tx_delay[4] = {0, 0, 0, 0};    // The delay that is being transmitted
static uint32_t curr_delay[4] = {0, 0, 0, 0};  // The current delay that is being sampled and averaged
uint32_t sample_index = 0;
uint8_t tx_flag = 0;                // For determining if we should tx or not
uint8_t var_mux_state = 0;  // Variables for tracking mux state
uint8_t channel_idx = 0;    // Variable for keeping track of current delay channel being read.

//int ScanChain_input [SC_size] = {SC_ES,SC_RSTN,SC_EXT_SEL,SC_DIV_SEL,SC_TAP_SEL,SC_CLK,SC_CLK_ST,SC_MAX_VAL,SC_G,SC_FB,SC_ATDE_RST};
int ScanChain_input [SC_size] = {0,0,0,0,0,0,0,0,0,0,0,0,0,0,0,0,1,0,1,0,0,0,0,0,0,0,0,0,0,0,1,1,1,1,1,1,0,0,1,0,0,0};
int ScanChain_output [SC_size];

// Prototypes
static uint8_t ScanChain_rotate(int* input, int Size);
static void stm_exti_high(void);
static void stm_exti_low(void);
static void data_pins_init(void);
static void signal_pins_init(void);
static void S0_high(void);
static void S0_low(void);
static void S0_toggle(void);
static void S1_high(void);
static void S1_low(void);
static void S1_toggle(void);

/**@brief Function for assert macro callback.
 *
 * @details This function will be called in case of an assert in the SoftDevice.
 *
 * @warning This handler is an example only and does not fit a final product. You need to analyse
 *          how your product is supposed to react in case of Assert.
 * @warning On assert from the SoftDevice, the system can only recover on reset.
 *
 * @param[in] line_num    Line number of the failing ASSERT call.
 * @param[in] p_file_name File name of the failing ASSERT call.
 */
void assert_nrf_callback(uint16_t line_num, const uint8_t * p_file_name)
{
    app_error_handler(DEAD_BEEF, line_num, p_file_name);
}


/**@brief Function for the GAP initialization.
 *
 * @details This function will set up all the necessary GAP (Generic Access Profile) parameters of
 *          the device. It also sets the permissions and appearance.
 */
static void gap_params_init(void)
{
    uint32_t                err_code;
    ble_gap_conn_params_t   gap_conn_params;
    ble_gap_conn_sec_mode_t sec_mode;

    BLE_GAP_CONN_SEC_MODE_SET_OPEN(&sec_mode);

    err_code = sd_ble_gap_device_name_set(&sec_mode,
                                          (const uint8_t *) DEVICE_NAME,
                                          strlen(DEVICE_NAME));
    APP_ERROR_CHECK(err_code);

    memset(&gap_conn_params, 0, sizeof(gap_conn_params));

    gap_conn_params.min_conn_interval = MIN_CONN_INTERVAL;
    gap_conn_params.max_conn_interval = MAX_CONN_INTERVAL;
    gap_conn_params.slave_latency     = SLAVE_LATENCY;
    gap_conn_params.conn_sup_timeout  = CONN_SUP_TIMEOUT;

    err_code = sd_ble_gap_ppcp_set(&gap_conn_params);
    APP_ERROR_CHECK(err_code);
																					
		err_code = sd_ble_gap_tx_power_set(0);
		APP_ERROR_CHECK(err_code);
}

// Add custom rx characteristic
static uint32_t custom_rx_char_add(ble_nus_t * p_nus, const ble_nus_init_t * p_nus_init)
{
    /**@snippet [Adding proprietary characteristic to S110 SoftDevice] */
    ble_gatts_char_md_t char_md;
    ble_gatts_attr_md_t cccd_md;
    ble_gatts_attr_t    attr_char_value;
    ble_uuid_t          ble_uuid;
    ble_gatts_attr_md_t attr_md;

    memset(&cccd_md, 0, sizeof(cccd_md));

    BLE_GAP_CONN_SEC_MODE_SET_OPEN(&cccd_md.read_perm);
    BLE_GAP_CONN_SEC_MODE_SET_OPEN(&cccd_md.write_perm);

    cccd_md.vloc = BLE_GATTS_VLOC_STACK;

    memset(&char_md, 0, sizeof(char_md));

    char_md.char_props.notify = 1;
    char_md.p_char_user_desc  = NULL;
    char_md.p_char_pf         = NULL;
    char_md.p_user_desc_md    = NULL;
    char_md.p_cccd_md         = &cccd_md;
    char_md.p_sccd_md         = NULL;

    ble_uuid.type = p_nus->uuid_type;
    ble_uuid.uuid = 0x1234;

    memset(&attr_md, 0, sizeof(attr_md));

    BLE_GAP_CONN_SEC_MODE_SET_OPEN(&attr_md.read_perm);
    BLE_GAP_CONN_SEC_MODE_SET_OPEN(&attr_md.write_perm);

    attr_md.vloc    = BLE_GATTS_VLOC_STACK;
    attr_md.rd_auth = 0;
    attr_md.wr_auth = 0;
    attr_md.vlen    = 1;

    memset(&attr_char_value, 0, sizeof(attr_char_value));

    attr_char_value.p_uuid    = &ble_uuid;
    attr_char_value.p_attr_md = &attr_md;
    attr_char_value.init_len  = sizeof(uint8_t);
    attr_char_value.init_offs = 0;
    attr_char_value.max_len   = (GATT_MTU_SIZE_DEFAULT - 3);

    return sd_ble_gatts_characteristic_add(p_nus->service_handle,
                                           &char_md,
                                           &attr_char_value,
                                           &p_nus->rx_handles);
    /**@snippet [Adding proprietary characteristic to S110 SoftDevice] */
}

// Handles the handshaking process between ble and stm as well as between ble and app whenever disconnect happens
static uint32_t handle_handshake_end(void)
{
	uint8_t i;
	send = 0;
	
	// Send stop message to STM32
	//stm_exti_low();
	
	return sd_ble_gap_disconnect(m_conn_handle,
                               BLE_HCI_REMOTE_USER_TERMINATED_CONNECTION);
}

// Handles the handshaking process between ble and stm as well as between ble and app whenever connection happens
static uint32_t handle_handshake_start(void)
{
	uint8_t i;
	send = 1;
	
	// Send start message to STM32
	//stm_exti_high();
	
	return NRF_SUCCESS;
}

/**@brief Function for handling the data from the Nordic UART Service.
 *
 * @details This function will process the data received from the Nordic UART BLE Service and send
 *          it to the UART module.
 *
 * @param[in] p_nus    Nordic UART Service structure.
 * @param[in] p_data   Data to be send to UART module.
 * @param[in] length   Length of the data.
 */
/**@snippet [Handling the data received over BLE] */
static void nus_data_handler(ble_nus_t * p_nus, uint8_t * p_data, uint16_t length)
{
	  uint32_t err_code;
	  //send = send ^ 1;
	  // Parse Start and stop messages
		if(length >= 5) {
			
			// Start MESSAGE: SEUSS
			if(p_data[0] == 83 && p_data[1] == 69 && p_data[2] == 85 && p_data[3] == 83 && p_data[4] == 83) {
			  start = 1;
				
			}
			
			// Start MESSAGE: SEUSE
			if(p_data[0] == 83 && p_data[1] == 69 && p_data[2] == 85 && p_data[3] == 83 && p_data[4] == 69) {
			  stop = 1;
			}
		}
	
    /*for (uint32_t i = 0; i < length; i++)
    {
        while (app_uart_put(p_data[i]) != NRF_SUCCESS);
    }
    while (app_uart_put('\r') != NRF_SUCCESS);
    while (app_uart_put('\n') != NRF_SUCCESS);*/
}
/**@snippet [Handling the data received over BLE] */


/**@brief Function for initializing services that will be used by the application.
 */
static void services_init(void)
{
    uint32_t       err_code;
    ble_nus_init_t nus_init;

    memset(&nus_init, 0, sizeof(nus_init));

    nus_init.data_handler = nus_data_handler;

    err_code = ble_nus_init(&m_nus, &nus_init);
    APP_ERROR_CHECK(err_code);
	
	  //err_code = custom_rx_char_add(&m_nus, &nus_init);
		//APP_ERROR_CHECK(err_code);
	
}


/**@brief Function for handling an event from the Connection Parameters Module.
 *
 * @details This function will be called for all events in the Connection Parameters Module
 *          which are passed to the application.
 *
 * @note All this function does is to disconnect. This could have been done by simply setting
 *       the disconnect_on_fail config parameter, but instead we use the event handler
 *       mechanism to demonstrate its use.
 *
 * @param[in] p_evt  Event received from the Connection Parameters Module.
 */
static void on_conn_params_evt(ble_conn_params_evt_t * p_evt)
{
    uint32_t err_code;

    if (p_evt->evt_type == BLE_CONN_PARAMS_EVT_FAILED)
    {
        err_code = sd_ble_gap_disconnect(m_conn_handle, BLE_HCI_CONN_INTERVAL_UNACCEPTABLE);
        APP_ERROR_CHECK(err_code);
    }
}


/**@brief Function for handling errors from the Connection Parameters module.
 *
 * @param[in] nrf_error  Error code containing information about what went wrong.
 */
static void conn_params_error_handler(uint32_t nrf_error)
{
    APP_ERROR_HANDLER(nrf_error);
}


/**@brief Function for initializing the Connection Parameters module.
 */
static void conn_params_init(void)
{
    uint32_t               err_code;
    ble_conn_params_init_t cp_init;

    memset(&cp_init, 0, sizeof(cp_init));

    cp_init.p_conn_params                  = NULL;
    cp_init.first_conn_params_update_delay = FIRST_CONN_PARAMS_UPDATE_DELAY;
    cp_init.next_conn_params_update_delay  = NEXT_CONN_PARAMS_UPDATE_DELAY;
    cp_init.max_conn_params_update_count   = MAX_CONN_PARAMS_UPDATE_COUNT;
    cp_init.start_on_notify_cccd_handle    = BLE_GATT_HANDLE_INVALID;
    cp_init.disconnect_on_fail             = false;
    cp_init.evt_handler                    = on_conn_params_evt;
    cp_init.error_handler                  = conn_params_error_handler;

    err_code = ble_conn_params_init(&cp_init);
    APP_ERROR_CHECK(err_code);
}


/**@brief Function for putting the chip into sleep mode.
 *
 * @note This function will not return.
 */
static void sleep_mode_enter(void)
{
    uint32_t err_code = bsp_indication_set(BSP_INDICATE_IDLE);
    APP_ERROR_CHECK(err_code);

    // Prepare wakeup buttons.
    err_code = bsp_btn_ble_sleep_mode_prepare();
    APP_ERROR_CHECK(err_code);

    // Go to system-off mode (this function will not return; wakeup will cause a reset).
    err_code = sd_power_system_off();
    APP_ERROR_CHECK(err_code);
}


/**@brief Function for handling advertising events.
 *
 * @details This function will be called for advertising events which are passed to the application.
 *
 * @param[in] ble_adv_evt  Advertising event.
 */
static void on_adv_evt(ble_adv_evt_t ble_adv_evt)
{
    uint32_t err_code;

    switch (ble_adv_evt)
    {
        case BLE_ADV_EVT_FAST:
            err_code = bsp_indication_set(BSP_INDICATE_ADVERTISING);
            APP_ERROR_CHECK(err_code);
            break;
        case BLE_ADV_EVT_IDLE:
            sleep_mode_enter();
            break;
        default:
            break;
    }
}
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
int main(void)
{
    uint32_t err_code;
    bool erase_bonds;
	
	  // Start high frequency clock
		NRF_CLOCK->TASKS_HFCLKSTART = 1; 
    while(NRF_CLOCK->EVENTS_HFCLKSTARTED == 0); 

    // Initialize.
    APP_TIMER_INIT(APP_TIMER_PRESCALER, APP_TIMER_OP_QUEUE_SIZE, false);
    //uart_init();
	  //printf("\r\nUART Start!\r\n");

    //buttons_leds_init(&erase_bonds);
    ble_stack_init();
    gap_params_init();
    services_init();
    advertising_init();
	  
		// Initialize reading from xcorr chip
		stm_exti_init();
		stm_exti_high();
		data_pins_init();
		signal_pins_init();
		
		nrf_gpio_pin_clear(XCORR_PHI_PIN);
		nrf_gpio_pin_clear(XCORR_PHIB_PIN);
		nrf_gpio_pin_clear(XCORR_SC_IN_PIN);
		nrf_gpio_pin_clear(XCORR_SC_i0O1_PIN);
		nrf_gpio_pin_clear(XCORR_SC_LOAD_PIN);
		nrf_gpio_pin_clear(XCORR_RESETN_PIN);
	
    //printf("\r\nUART Start!\r\n");
    err_code = ble_advertising_start(BLE_ADV_MODE_FAST);
    APP_ERROR_CHECK(err_code);
		
		/*nrf_delay_us(1000000);
		asic_setup();
		xcorr_pwm_enable();
		xcorr_pwm_input_enable();*/

    // Enter main loop.
    for (;;)
    {
      //power_manage();
			  
			// Start message received, wakeup STM to begin feature collection
			if(start)
			{
				start = 0;
				running = 1;
				asic_setup();
				xcorr_pwm_enable();
				xcorr_pwm_input_enable();
				//err_code = handle_handshake_start();
			  //APP_ERROR_CHECK(err_code);
			}
			
			// Stop message received, put STM to sleep
			else if(stop)
			{
				stop = 0;
				running = 0;
				xcorr_pwm_input_disable();
				xcorr_pwm_disable();
				err_code = handle_handshake_end();
			  APP_ERROR_CHECK(err_code);
			}
				//err_code = ble_nus_string_send(&m_nus, test_data, 1);
				
			else if(tx_flag) {
				tx_flag = 0;
				
				if(pwm_polarity_flag > 0)
				{
					//stm_exti_high();
					pwm_polarity_flag = 0;
				}
				else
				{
					//stm_exti_low();
					pwm_polarity_flag = 1;
				}
				
				tx_data();
			}
			
			//else if(!running) {
			//	power_manage();
			//}
    }
}


/**
 * @}
 */

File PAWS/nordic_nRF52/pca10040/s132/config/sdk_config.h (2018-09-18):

#ifndef SDK_CONFIG_H
#define SDK_CONFIG_H
// <<< Use Configuration Wizard in Context Menu >>>\n
#ifdef USE_APP_CONFIG
#include "app_config.h"
#endif
// <h> nRF_BLE 

//==========================================================
// <q> BLE_ADVERTISING_ENABLED  - ble_advertising - Advertising module
 

#ifndef BLE_ADVERTISING_ENABLED
#define BLE_ADVERTISING_ENABLED 1
#endif

// <q> BLE_DTM_ENABLED  - ble_dtm - Module for testing RF/PHY using DTM commands
 

#ifndef BLE_DTM_ENABLED
#define BLE_DTM_ENABLED 0
#endif

// <q> BLE_RACP_ENABLED  - ble_racp - Record Access Control Point library
 

#ifndef BLE_RACP_ENABLED
#define BLE_RACP_ENABLED 0
#endif

// <q> NRF_BLE_QWR_ENABLED  - nrf_ble_qwr - Queued writes support module (prepare/execute write)
 

#ifndef NRF_BLE_QWR_ENABLED
#define NRF_BLE_QWR_ENABLED 0
#endif

// <q> PEER_MANAGER_ENABLED  - peer_manager - Peer Manager
 

#ifndef PEER_MANAGER_ENABLED
#define PEER_MANAGER_ENABLED 0
#endif

// </h> 
//==========================================================

// <h> nRF_BLE_Services 

//==========================================================
// <q> BLE_ANCS_C_ENABLED  - ble_ancs_c - Apple Notification Service Client
 

#ifndef BLE_ANCS_C_ENABLED
#define BLE_ANCS_C_ENABLED 0
#endif

// <q> BLE_ANS_C_ENABLED  - ble_ans_c - Alert Notification Service Client
 

#ifndef BLE_ANS_C_ENABLED
#define BLE_ANS_C_ENABLED 0
#endif

// <q> BLE_BAS_C_ENABLED  - ble_bas_c - Battery Service Client
 

#ifndef BLE_BAS_C_ENABLED
#define BLE_BAS_C_ENABLED 0
#endif

// <q> BLE_BAS_ENABLED  - ble_bas - Battery Service
 

#ifndef BLE_BAS_ENABLED
#define BLE_BAS_ENABLED 0
#endif

// <q> BLE_CSCS_ENABLED  - ble_cscs - Cycling Speed and Cadence Service
 

#ifndef BLE_CSCS_ENABLED
#define BLE_CSCS_ENABLED 0
#endif

// <q> BLE_CTS_C_ENABLED  - ble_cts_c - Current Time Service Client
 

#ifndef BLE_CTS_C_ENABLED
#define BLE_CTS_C_ENABLED 0
#endif

// <q> BLE_DIS_ENABLED  - ble_dis - Device Information Service
 

#ifndef BLE_DIS_ENABLED
#define BLE_DIS_ENABLED 0
#endif

// <q> BLE_GLS_ENABLED  - ble_gls - Glucose Service
 

#ifndef BLE_GLS_ENABLED
#define BLE_GLS_ENABLED 0
#endif

// <q> BLE_HIDS_ENABLED  - ble_hids - Human Interface Device Service
 

#ifndef BLE_HIDS_ENABLED
#define BLE_HIDS_ENABLED 0
#endif

// <q> BLE_HRS_C_ENABLED  - ble_hrs_c - Heart Rate Service Client
 

#ifndef BLE_HRS_C_ENABLED
#define BLE_HRS_C_ENABLED 0
#endif

// <q> BLE_HRS_ENABLED  - ble_hrs - Heart Rate Service
 

#ifndef BLE_HRS_ENABLED
#define BLE_HRS_ENABLED 0
#endif

// <q> BLE_HTS_ENABLED  - ble_hts - Health Thermometer Service
 

#ifndef BLE_HTS_ENABLED
#define BLE_HTS_ENABLED 0
#endif

// <q> BLE_IAS_C_ENABLED  - ble_ias_c - Immediate Alert Service Client
 

#ifndef BLE_IAS_C_ENABLED
#define BLE_IAS_C_ENABLED 0
#endif

// <q> BLE_IAS_ENABLED  - ble_ias - Immediate Alert Service
 

#ifndef BLE_IAS_ENABLED
#define BLE_IAS_ENABLED 0
#endif

// <q> BLE_LBS_C_ENABLED  - ble_lbs_c - Nordic LED Button Service Client
 

#ifndef BLE_LBS_C_ENABLED
#define BLE_LBS_C_ENABLED 0
#endif

// <q> BLE_LBS_ENABLED  - ble_lbs - LED Button Service
 

#ifndef BLE_LBS_ENABLED
#define BLE_LBS_ENABLED 0
#endif

// <q> BLE_LLS_ENABLED  - ble_lls - Link Loss Service
 

#ifndef BLE_LLS_ENABLED
#define BLE_LLS_ENABLED 0
#endif

// <q> BLE_NUS_C_ENABLED  - ble_nus_c - Nordic UART Central Service
 

#ifndef BLE_NUS_C_ENABLED
#define BLE_NUS_C_ENABLED 0
#endif

// <q> BLE_NUS_ENABLED  - ble_nus - Nordic UART Service
 

#ifndef BLE_NUS_ENABLED
#define BLE_NUS_ENABLED 1
#endif

// <q> BLE_RSCS_C_ENABLED  - ble_rscs_c - Running Speed and Cadence Client
 

#ifndef BLE_RSCS_C_ENABLED
#define BLE_RSCS_C_ENABLED 0
#endif

// <q> BLE_RSCS_ENABLED  - ble_rscs - Running Speed and Cadence Service
 

#ifndef BLE_RSCS_ENABLED
#define BLE_RSCS_ENABLED 0
#endif

// <q> BLE_TPS_ENABLED  - ble_tps - TX Power Service
 

#ifndef BLE_TPS_ENABLED
#define BLE_TPS_ENABLED 0
#endif

// </h> 
//==========================================================

// <h> nRF_Drivers 

//==========================================================
// <e> ADC_ENABLED - nrf_drv_adc - Driver for ADC peripheral (nRF51)
//==========================================================
#ifndef ADC_ENABLED
#define ADC_ENABLED 0
#endif
#if  ADC_ENABLED
// <o> ADC_CONFIG_IRQ_PRIORITY  - Interrupt priority
 

// <i> Priorities 0,2 (nRF51) and 0,1,4,5 (nRF52) are reserved for SoftDevice
// <0=> 0 (highest) 
// <1=> 1 
// <2=> 2 
// <3=> 3 
// <4=> 4 
// <5=> 5 
// <6=> 6 
// <7=> 7 

#ifndef ADC_CONFIG_IRQ_PRIORITY
#define ADC_CONFIG_IRQ_PRIORITY 6
#endif

#endif //ADC_ENABLED
// </e>

// <e> CLOCK_ENABLED - nrf_drv_clock - CLOCK peripheral driver
//==========================================================
#ifndef CLOCK_ENABLED
#define CLOCK_ENABLED 1
#endif
#if  CLOCK_ENABLED
// <o> CLOCK_CONFIG_XTAL_FREQ  - HF XTAL Frequency
 
// <0=> Default (64 MHz) 

#ifndef CLOCK_CONFIG_XTAL_FREQ
#define CLOCK_CONFIG_XTAL_FREQ 0
#endif

// <o> CLOCK_CONFIG_LF_SRC  - LF Clock Source
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

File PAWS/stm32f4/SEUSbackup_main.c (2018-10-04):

/**
  ******************************************************************************
  * @file    Project/STM32F4xx_StdPeriph_Templates/main.c 
  * @author  MCD Application Team
  * @version V1.7.1
  * @date    20-May-2016
  * @brief   Main program body
  ******************************************************************************
  * @attention
  *
  * <h2><center>&copy; COPYRIGHT 2016 STMicroelectronics</center></h2>
  *
  * Licensed under MCD-ST Liberty SW License Agreement V2, (the "License");
  * You may not use this file except in compliance with the License.
  * You may obtain a copy of the License at:
  *
  *        http://www.st.com/software_license_agreement_liberty_v2
  *
  * Unless required by applicable law or agreed to in writing, software 
  * distributed under the License is distributed on an "AS IS" BASIS, 
  * WITHOUT WARRANTIES OR CONDITIONS OF ANY KIND, either express or implied.
  * See the License for the specific language governing permissions and
  * limitations under the License.
  *
  ******************************************************************************
  *
  *
  * MIT License
  *
  * Copyright (c) 2018, Stephen Xia, Columbia Intelligent and Connected Systems Lab (ICSL), Columbia University
  *
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
  * THE SOFTWARE IS PROVIDED “AS IS”, WITHOUT WARRANTY OF ANY KIND, EXPRESS OR
  * IMPLIED, INCLUDING BUT NOT LIMITED TO THE WARRANTIES OF MERCHANTABILITY,
  * FITNESS FOR A PARTICULAR PURPOSE AND NONINFRINGEMENT. IN NO EVENT SHALL THE
  * AUTHORS OR COPYRIGHT HOLDERS BE LIABLE FOR ANY CLAIM, DAMAGES OR OTHER
  * LIABILITY, WHETHER IN AN ACTION OF CONTRACT, TORT OR OTHERWISE, ARISING FROM,
  * OUT OF OR IN CONNECTION WITH THE SOFTWARE OR THE USE OR OTHER DEALINGS IN THE
  * SOFTWARE.
  */

/* Includes ------------------------------------------------------------------*/
#include "main.h"

/** @addtogroup Template_Project
  * @{
  */ 

/* Private typedef -----------------------------------------------------------*/

typedef enum 
{
  LED1 = 0,
  LED2 = 1,
  LED3 = 2,
  LED4 = 3
} Led_TypeDef;

typedef struct {
	int max_point_channel_2;  //int
	int max_point_channel_3;
	int max_point_channel_4;

	long long int power_1;          //long long int
	long long int related_power_2;
	long long int related_power_3;
	long long int related_power_4;

	int zero_crossing_rate_1;  //int
	int zero_crossing_rate_2;
	int zero_crossing_rate_3;
	int zero_crossing_rate_4;
	
	unsigned char mic_flags;     // Sent to app to see if the microphones are on or off: 0 is on, 1 is off.

} DataCalculationType;



/* Private define ------------------------------------------------------------*/

#define WINDOW_SIZE 3200          // Window size for each channel

#define BUFFER_SIZE WINDOW_SIZE * 4/2   // Buffer size for 4 channels; 50% overlap
#define C_BUFFER_SIZE WINDOW_SIZE * 4 // Size of the calculation buffer;
#define SAMPLING_FREQ 32000     // Sampling frequency for each channel
#define MAX_DELAY 40            // Max delay in channels.

#define LEDn 4
#define LED1_PIN                         GPIO_Pin_5
#define LED1_GPIO_PORT                   GPIOA
#define LED1_GPIO_CLK                    RCC_AHB1Periph_GPIOA  
  
#define LED2_PIN                         GPIO_Pin_8
#define LED2_GPIO_PORT                   GPIOG
#define LED2_GPIO_CLK                    RCC_AHB1Periph_GPIOG  
  
#define LED3_PIN                         GPIO_Pin_9
#define LED3_GPIO_PORT                   GPIOI
#define LED3_GPIO_CLK                    RCC_AHB1Periph_GPIOI  
  
#define LED4_PIN                         GPIO_Pin_7
#define LED4_GPIO_PORT                   GPIOC
#define LED4_GPIO_CLK                    RCC_AHB1Periph_GPIOC

// ADC defines
#define NUM_CONVERSIONS 4

#define CH1_ADC_CHx ADC_Channel_0
#define CH1_GPIO GPIOA
#define CH1_GPIO_PINx GPIO_Pin_0
#define CH1_ADCx ADC1

#define CH2_ADC_CHx ADC_Channel_1
#define CH2_GPIO GPIOA
#define CH2_GPIO_PINx GPIO_Pin_1
#define CH2_ADCx ADC1

#define CH3_ADC_CHx ADC_Channel_4
#define CH3_GPIO GPIOA
#define CH3_GPIO_PINx GPIO_Pin_4
#define CH3_ADCx ADC1

#define CH4_ADC_CHx ADC_Channel_8
#define CH4_GPIO GPIOB
#define CH4_GPIO_PINx GPIO_Pin_0
#define CH4_ADCx ADC1

GPIO_TypeDef* GPIO_PORT[LEDn] = {LED1_GPIO_PORT, LED2_GPIO_PORT, LED3_GPIO_PORT,
                                 LED4_GPIO_PORT};
const uint16_t GPIO_PIN[LEDn] = {LED1_PIN, LED2_PIN, LED3_PIN,
                                 LED4_PIN};
const uint32_t GPIO_CLK[LEDn] = {LED1_GPIO_CLK, LED2_GPIO_CLK, LED3_GPIO_CLK,
                                 LED4_GPIO_CLK};

/* Private macro -------------------------------------------------------------*/
/* Private variables ---------------------------------------------------------*/

static __IO uint32_t uwTimingDelay;
RCC_ClocksTypeDef RCC_Clocks;
//void Delay(__IO uint32_t nTime);

GPIO_InitTypeDef 		GPIO_InitStructure_ADC_ch1;
GPIO_InitTypeDef 		GPIO_InitStructure_ADC_ch2;
GPIO_InitTypeDef 		GPIO_InitStructure_ADC_ch3;
GPIO_InitTypeDef 		GPIO_InitStructure_ADC_ch4;
GPIO_InitTypeDef 		GPIO_InitStructure_UART;
ADC_InitTypeDef 		ADC_InitStructure;
ADC_CommonInitTypeDef 	ADC_CommonInitStructure;
DMA_InitTypeDef 		DMA_InitStructure;
NVIC_InitTypeDef NVIC_InitStructure;
TIM_TimeBaseInitTypeDef TIM_TimeBaseStructure;
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

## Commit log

2018-09-18 Adding project files, README, and License files.
    [STM32F437IIHx_CustomBoard.cfg]
2018-10-04 Updating licensing and and README to all source code. Added explanations on how to reproduce the front-end system and how to flash and build custom source code.
    [BOM_PartType-ICSL PS Combined.xls, BOM_PartType-ICSL PS REV 0_2.xls, ICSL PS Combined.PrjPcb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]
2018-10-24 Deleting PAWS_LE Front-End PCB Design Files.
    [BOM_PartType-ICSL PS REV 0_2.xls, ICSL PS REV 0_2.PrjPcb, ICSL_PS_BMD.SchDoc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]
2018-10-24 Adding new PAWS_LE pcb files containing values of all capacitors and resistors labeled.
    [BOM_PartType-ICSL PS REV 0_2.xls, ICSL PS REV 0_2.PrjPcb, ICSL_PS_BMD.SchDoc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]
2018-10-24 Deleting PAWS PCB design files.
    [BOM_PartType-ICSL PS Combined.xls, ICSL PS Combined.PrjPcb, ICSL_PS_Combined_BMD.SchDoc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]
2018-10-24 Adding PAWS pcb files and MEMS microphone pcb files with labeled resistor and capacitor values.
    [BOM_PartType-ICSL PS Combined.xls, BOM_PartType-MEMS_MIC_V0.xls, ICSL PS Combined.PrjPcb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]
2018-10-25 Adding instructions on how to access pcb designs using Altium Circuit Maker and how to flash the controllers in the PAWS systems.
2018-10-25 Adding parts required for flashing firmware onto BLE and STM32F4.
2018-12-14 Adding Headset_Assembly.pdf, which details how to assemble the PAWS headset.

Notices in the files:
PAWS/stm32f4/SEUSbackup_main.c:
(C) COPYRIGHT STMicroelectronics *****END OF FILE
